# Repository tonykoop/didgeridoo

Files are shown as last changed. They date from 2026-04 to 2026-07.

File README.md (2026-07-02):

# Didgeridoo — Engineering Documentation for a Stave-Built Wind Instrument

> *A 2013 acoustic study of stave-built didgeridoos across 25 musical keys, plus the engineering documentation, CAD work, and design brainstorming that has accumulated around it since.*

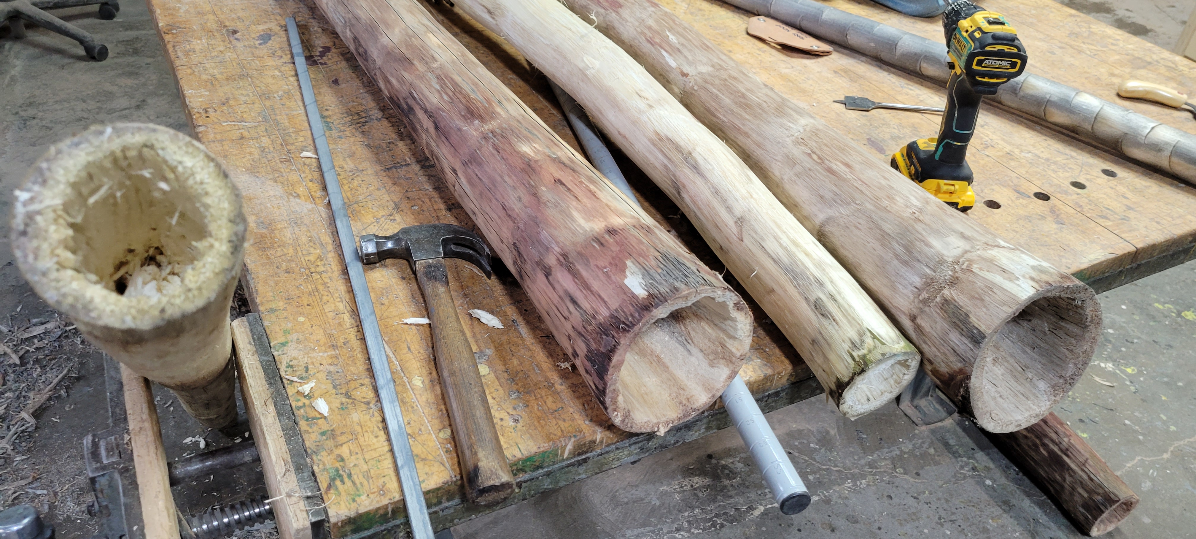
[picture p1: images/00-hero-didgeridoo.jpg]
Hero photo

*Didgeridoo blanks and rough-bored bodies on the shop bench — the physical side of the stave-built wind-instrument problem before the acoustic-length math turns into a finished bore.*

## What this is

Engineering documentation for the **stave-built didgeridoo** — a long Australian Aboriginal wind instrument that is traditionally made from a single eucalyptus branch hollowed by termites, but that I have been studying as a precision stave-construction problem since 2013.

The repository combines three threads:

1. **A 2013 acoustic study** I conducted in my engineering notebook covering 25 musical keys (C1–C3, with build lengths from ~27" at C3 up to ~107" at C1), with frequency, wavelength, build length, and stave-width calculations for each key.
2. **CAD geometry** for stave-built didgeridoo bodies derived from that table.
3. **Brainstorming and design work** on internal-surface treatments — smooth, ribbed, concentric-ringed — that shape the instrument's harmonic content.

Sister project to [`djembe`](https://github.com/tonykoop/djembe), [`dundun`](https://github.com/tonykoop/dundun), and [`ashiko-drum-workshop`](https://github.com/tonykoop/ashiko-drum-workshop).

## Background

The didgeridoo (also yiḏaki, mago, and many regional names) is a wind instrument with origins in the cultures of the **Aboriginal peoples of northern Australia**, with continuous documented use for at least 1,500 years and likely much longer. Traditional didgeridoos are made by finding a eucalyptus or bamboo branch hollowed naturally by termites, then trimming and shaping it for sound — a process that yields a unique instrument every time but offers no precise control over pitch or tone.

A **stave-built** didgeridoo is a Western maker's adaptation: rather than relying on termite excavation, the bore is built up from precisely-cut wooden staves glued in a parallel bundle. This trades the natural variability of the traditional instrument for **the ability to target a specific key, length, and bore profile by design.** It also makes locally-sourced North American hardwoods viable — oak, maple, cherry, padauk, and so on — instead of depending on Australian eucalyptus.

## The engineering challenge

A didgeridoo's fundamental frequency is set by the **acoustic length of the bore** and modified by mouthpiece, bell, and bore taper. The basic relationship for a closed-pipe (lip-blown) instrument is:

```
f ≈ c / (4 × L)
```

where `f` is fundamental frequency, `c` is speed of sound at the playing temperature (~37 °C for warm exhaled breath = ~351.8 m/s), and `L` is the effective acoustic length.

In my 2013 notebook study I calculated build dimensions for **25 keys from C1 (32.7 Hz, ~107" long) to C3 (130.8 Hz, ~27" long)**, with stave widths and inner diameters tabulated across three length-to-diameter aspect ratios: 22:1, 24:1, and 26:1. The L:D ratio governs the slenderness of the instrument — at a given length, a narrower bore (higher L:D) produces a darker tone with stronger upper harmonics; a fatter bore yields a brighter, more open sound.

The engineering interest of stave construction is precision: cutting 6, 8, or 12 staves with the right width, taper, and bevel angle to assemble into a target bore is much more controllable than excavating a branch. The stave geometry depends on the target bore diameter and stave count — calculable from the 2013 table.

## Acoustic research

The primary source for this repository is a 2013 lab-notebook entry (witnessed/signed/dated), pictured below:

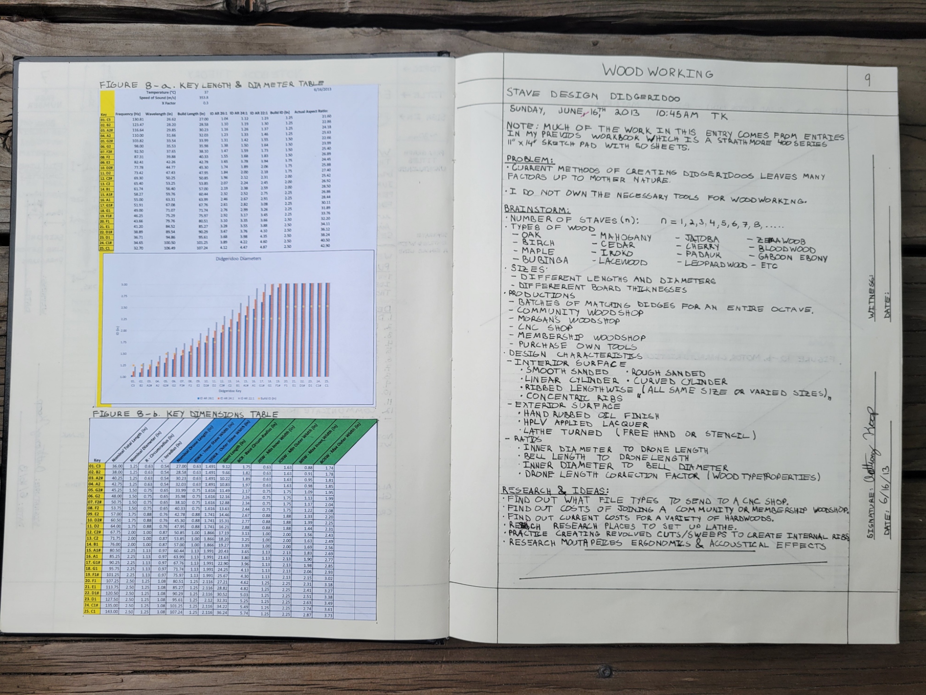
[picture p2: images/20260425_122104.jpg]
2013 didgeridoo notebook entry — Sunday June 16, 2013, page 9

*The notebook spread: Figure 8-a Key Length & Diameter Table (25 chromatic keys C1–C3), Didgeridoo Diameters bar chart, Figure 8-b Key Dimensions Table, plus brainstorming on stave count, wood species, production paths, and design characteristics. Witnessed and dated.*

Contents of that entry:

- **Figure 8-a — Key Length & Diameter Table.** 25 rows, one per chromatic key from C1 to C3, with fundamental frequency, wavelength at 37 °C, build length, ID at 26:1 / 24:1 / 22:1 aspect ratios, build ID, and actual aspect ratio.
- **Didgeridoo Diameters bar chart** — visual comparison of inner diameters across all 25 keys.
- **Figure 8-b — Key Dimensions Table.** Nominal total length, nominal diameter, outer/inner radius, drone length, stave widths (inner and outer), bevel widths, and minimum/maximum widths per key.
- **Brainstorming notes** on stave count (n = 1 through 8+), wood types (oak, mahogany, cherry, jatoba, maple, lacewood, padauk, etc.), production paths (CNC, community woodshop, Morgan's woodshop, membership shop), and design characteristics (interior surface variants, exterior finishes, bore aspect ratios).
- **Research questions** noted for follow-up: file types accepted by CNC shops, costs of various hardwoods, lathe sourcing, internal-rib practice cuts, mouthpiece ergonomics and acoustic effects.

The notebook page is the closest thing this repository has to a primary source. The entire CAD and jig design effort is downstream of that table.

## CAD and jig design

The first CAD authority pass is now scoped as a bore-station measurement
capture, not as a build-ready bore claim. See:

- `analysis/bore-station-measurement-plan.md` for datum, station, and review
  rules.
- `analysis/bore-station-station-map.csv` for normalized station IDs.
- `analysis/bore-station-measurement-log.csv` for the empty measurement table
  that must be populated before geometry authority exists.
- `CAD/bore-profile/didgeridoo-bore-starter.scad` for a non-fabrication
  OpenSCAD starter that renders station markers until measured bore diameters
  are supplied.
- `drawings/didgeridoo-bore-dxf-authority-plan.md` for the future DXF layer and
  review gate.

Repository structure is laid out for:

- `/CAD/bore-profile/` — the target inner-bore geometry for one or more keys, parametric in length and aspect ratio.
- `/CAD/stave/` — stave geometry derived from the bore profile, varying with stave count `n` and target key.
- `/CAD/jigs/` — the cutting fixtures. Likely one for the bevel angle (similar to the ashiko sled) and one for the optional internal-rib feature (a router fixture or lathe template).

## Build history

> *(Forthcoming — pulling whatever physical builds and prototype photos exist into `/images/`.)*

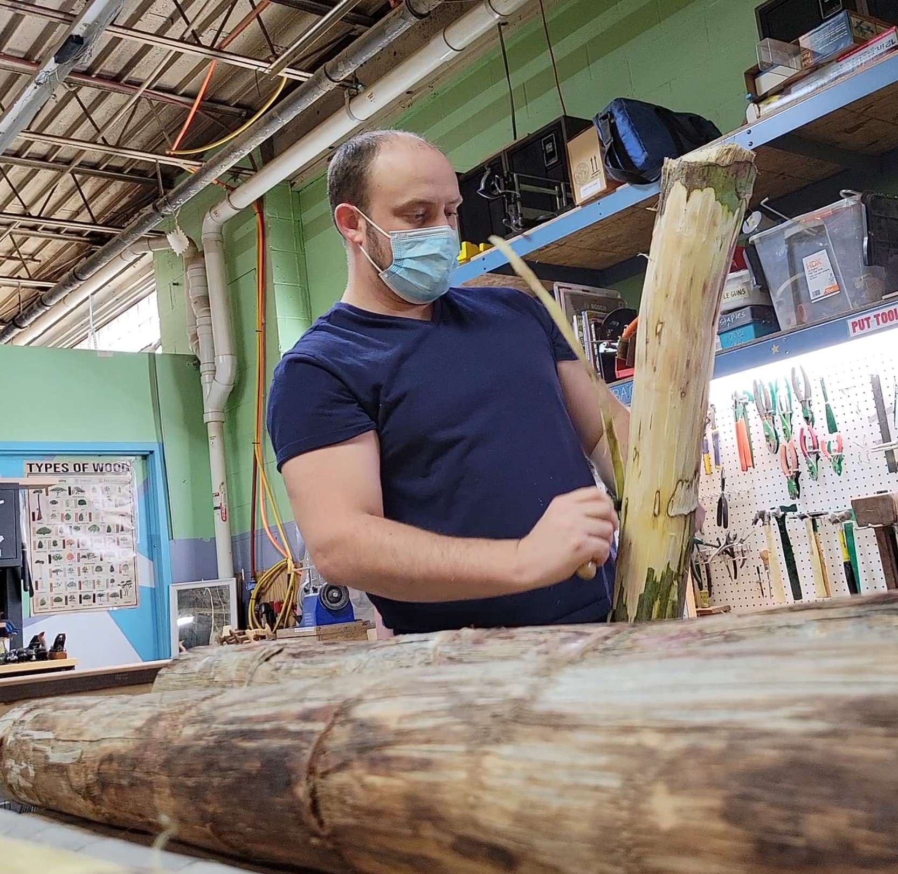
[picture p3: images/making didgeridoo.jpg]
Stripping bark from a raw didgeridoo log in the shop

*In the shop with a peeled didgeridoo log — early stage of a stave-built (or hybrid) build before the bore is established.*

## What this work is for

- **The acoustic question** — calibrating the table against measured pitch from physical builds. Does a stave-built didgeridoo built to the calculated dimensions actually play in tune?
- **The fabrication question** — which combination of stave count, wood selection, and aspect ratio produces the easiest-to-build, best-sounding instrument?
- **The portfolio frame** — for engineers and recruiters: this repository documents an analytical engineering practice (parametric design tables, bore acoustics, stave fabrication math) that I have been refining since 2013, in parallel with my professional engineering career.

## License

Released under [CC-BY 4.0](LICENSE) — use freely with attribution. The didgeridoo as an instrument originates with Aboriginal Australian cultures and has continuous traditional use; the stave-construction methodology, acoustic calculations, CAD work, and analysis in this repository are my own work, free to reuse and adapt with credit.

## Repository structure

```
didgeridoo/
├── README.md                  ← you are here
├── LICENSE                    ← CC-BY 4.0
├── .gitignore
├── research/                  ← 2013 notebook entry + acoustic refs
├── analysis/                  ← parametric calculations, FFT plots (forthcoming)
├── CAD/
│   ├── bore-profile/          ← target inner geometry, by key
│   ├── stave/                 ← stave geometry by key and stave count
│   └── jigs/                  ← bevel sled + optional internal-rib jig
├── drawings/                  ← PDF exports
├── images/                    ← finished-build photos + figures
└── reference/                 ← any reference documents
```

## Status

**Status:** L1 concept packet

Packet readiness: `L1_packet` / V5-shaped starter slice. Fabrication authority
is not released; CAD/DXF/design-table authority still requires measured bore
stations or reviewed parametric geometry.

## Starter Packet Surfaces

Open `explorer.html` for a studio-facing overview of the current bare-bones
packet. `site/index.html` redirects to that explorer until a fuller public
build-log site is ready.

Core packet files:

- `design.md` - A1 bell-flared candidate, stopped-pipe assumptions, and
  measurement-required unknowns.
- `bom.csv`, `sourcing.csv`, and `cut-list.csv` - starter planning rows only;
  purchase-time availability and prices remain unverified.
- `validation.csv` and `validation-loop.csv` - bore, pitch, leak, trim, and
  breath-contact safety gates.
- `risks.md` and `photo-shotlist.md` - validation risks and documentation shots
  for a future build.
- `capstone-manifest.json` - machine-readable inventory and public-release
  blockers.
- `evolution/` - Stage 0 evolution-pipeline intake (design intent, revision
  register, master manifest with sha256 provenance) for `CAD/didgeridoo.scad`
  and the design-table/wolfram sources it traces to. Gate A not yet run.

| Section | Status |
|---|---|
| Repo description, license, gitignore | ✓ done |
| 2013 notebook entry (primary source) | ✓ photographed and committed |
| Hero photo | forthcoming |
| Bore station measurement plan | B5 starter added; no measured bore geometry claimed |
| CAD — bore profile geometry | blocked on populated bore-station measurements |
| CAD — stave geometry | not started |
| CAD — jig designs | not started |
| Physical builds | searching personal archives |

Living document — the primary-source acoustics table is already in place; CAD geometry and recovered physical-build documentation are the main remaining additions.

See `v5-packet-alignment.md` for the current V5 gap map and issue #1 closure
boundary.
The current B5 OpenSCAD/DXF work is an authority plan and capture scaffold
only.

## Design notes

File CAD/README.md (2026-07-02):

# CAD Notes

`didgeridoo.scad` is the current parametric bore-flare **envelope** master.
Authority: `pending_measurement` — see `visual-output-register.csv` CAD-001
and `mcp-session-log.md`. It does not replace or supersede
`bore-profile/didgeridoo-bore-starter.scad`, which stays the station-capture
template for recording real measurements.

## Why an envelope, not a bore profile

Didgeridoos have a flaring bore (narrow mouthpiece end, wide bell/foot end)
rather than a tone-hole schedule. `family-spec.csv` gives real design-table
mouth ID, bell/foot ID, and blank length for three candidate bore families
(`bell`, `conical`, `cylindrical`), but `analysis/bore-station-measurement-log.csv`
is currently **fully unmeasured** — every one of the 12 stations in
`analysis/bore-station-station-map.csv` is `unmeasured`. There is no interior
taper schedule in this repo to loft from, and `design.md` only describes the
bell family's interior shape in prose ("gradual expansion from mouth opening
toward bell") with no formula.

`didgeridoo.scad` handles the three families honestly and differently:

- **cylindrical** — mouth ID equals foot/bell ID by definition. Every
  interior station is set to the design-table mouth ID exactly. No
  assumption.
- **conical** — a straight-sided cone by definition. Every interior station
  is the exact linear interpolation between the design-table mouth ID and
  foot/bell ID. No assumption (this is what "conical" means).
- **bell** — no interior-taper formula exists anywhere in this repo. The
  master exposes `bell_show_assumption_curve` (default `true`, so the file
  always renders something for shop review): when true it fills interior
  stations with one clearly-labeled `bell_flare_exponent_assumption` curve
  (an assumption, not authority); when false the interior stations fall back
  to the `-1` TBD sentinel (same convention as
  `bore-profile/didgeridoo-bore-starter.scad`) and the module renders a flat
  station-check plate instead of a solid.

## Parameters

`profile` selects one of the three `family-spec.csv` rows
(`DID-V5-A1-BELL-P0` / `DID-V5-C2-CONICAL-P0` / `DID-V5-D2-CYL-P0`).
`wall_thickness_in` (0.50 in) comes from `design.md`'s Source Basis workbook
input; `CAD/didgeridoo-openscad-authority-plan.md` still flags wall thickness
as measurement-required for the as-built prototype, so treat it as a planning
assumption, not a confirmed as-built value. `fabrication_mode` /
`measurement_reviewed` gate fabrication the same way
`bore-profile/didgeridoo-bore-starter.scad` does — flipping `fabrication_mode`
alone can never make this master fabrication authority; `measurement_reviewed`
only becomes true after a real, reviewed pass over
`analysis/bore-station-measurement-log.csv`.

Render check: `openscad -o /tmp/didgeridoo-check.stl CAD/didgeridoo.scad`
exits 0 for the default `profile = "bell"` (assumption curve on).

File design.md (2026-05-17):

# Didgeridoo V5 Starter Design

Current status: bare-bones readiness packet.

Fabrication authority: not build-ready. The existing workbook and this packet
define a measured-build starting point, not final CAD/CAM geometry. CAD/DXF
status is future authority until a measured bore profile or reviewed drawing is
added.

## Intent

V5 is a starter lift for a stave-built or split-blank didgeridoo packet. The
first useful build target is a practical A1 drone with a bell-flared bore:

- Target drone: A1, 55.00 Hz.
- Governing model: stopped pipe, `f = c / (4 * L_eff)`.
- Starter blank length: 67.50 in, using the workbook convention of theoretical
  quarter-wave length plus 6 in trim allowance, rounded up to 0.25 in.
- Mouthpiece opening: 1.50 in ID.
- Candidate bell opening: 3.50 in ID.
- Expected ideal resonances before measured correction: 165.00 Hz and
  275.00 Hz.

The A1 bell candidate is long enough to feel like a full didgeridoo and short
enough for first-round shop handling. C2 and D2 candidates are kept in
`family-spec.csv` as comparison rows, but V5 should validate one candidate
before multiplying variants.

## Source Basis

The starting values come from `didgeridoo-design-table.xlsx` and its
`Didgeridoo` worksheet:

- Speed of sound input: 343 m/s at 20 C.
- Wall thickness input: 0.50 in.
- Mouthpiece opening input: 1.50 in.
- Three bore families: cylindrical, conical, and bell.
- Build convention: cut long, then trim from the foot end to raise pitch.

The workbook formulas are treated as design evidence and planning data. They
are not enough by themselves to release a V5 build-ready packet, because the
actual mouthpiece compliance, bell end correction, bore roughness, leak path,
and player coupling have not been measured.

## Bore Profile

Recommended V5 starter profile: bell-flared A1.

Candidate profile definition:

- Mouth end: 1.50 in ID.
- Main body: gradual expansion from mouth opening toward bell.
- Bell end: 3.50 in ID.
- Length reference: 61.38 in first-order quarter-wave length at 20 C, plus
  6.00 in trim allowance in the rough blank.
- End condition: lips seal the mouthpiece end; foot/bell end is open.

Do not cut the internal bore from these notes alone. First create a station
table or CAD spline with measured datum points, then review the drawing against
the bore-profile register in `CAD/bore-profile/bore-profile-register.csv`.

## Mouthpiece

Starter mouthpiece assumption:

- 1.50 in opening at the wood body or wax ring.
- Beeswax or removable test ring for early playability.
- Final lip contact geometry is measurement-required.

Open measurements:

- Comfortable lip aperture for the intended player.
- Wax ring thickness and inner-edge radius.
- Whether the mouthpiece volume shifts the effective closed-end behavior.
- Leak check at wax/body interface after warm-up.

## Bell And End Condition

The didgeridoo is modeled as a stopped pipe: the player's lips close the mouth
end acoustically and the bell/foot is open. The bell opening is a strong
correction term, so the bell row stays preliminary until measured.

The workbook's K1 row uses an open-end correction of `0.6 * radius`. For the
3.50 in A1 bell that is 1.05 in. This packet records that as an assumption, not
as a final trim instruction. The validation loop must measure the real drone
and trim response before deciding whether to shorten the body by that amount.

## Materials And Process

Supported V5 process paths:

- PVC prototype: fastest acoustic validation of length, leak behavior, and
  mouthpiece feel.
- Agave stalk: natural-bore path when a suitable dried stalk exists.
- Split hardwood blank: CNC/lathe path for controlled bore geometry.
- Stave-built hardwood: longer-term path after the bore station table and
  stave derivation are ready.

Preferred first validation path: PVC or inexpensive split-blank mockup. Do not
spend hardwood-CNC effort before the A1 length and mouthpiece assumptions have
passed a basic pitch/leak/response test.

## Unknowns Requiring Measurement

- Actual bore ID along the full length after boring, routing, sanding, and
  finishing.
- Fundamental pitch after mouthpiece is installed and warmed by playing.
- First toot / second resonance behavior relative to the ideal 3f prediction.
- Air leak behavior at glue seams, mouthpiece, and any natural cracks.
- Finish safety inside the bore after cure, including odor, tack, dust, and
  player contact risk.
- Whether bell flare moves the response closer to the desired tone or only
  makes tuning less predictable.
- Whether the final process is cylindrical, conical, bell-flared, or a hybrid
  found-bore profile.

## Promotion Gate

This packet can become a V5 build packet only after:

- `validation-loop.csv` has measured bore and pitch rows for the chosen
  candidate.
- A CAD/DXF/design-table artifact is named as fabrication authority.
- The starter BOM has in-hand or verified purchase-time sources.
- Finish and glue choices are confirmed safe for a breath-contact instrument.
- The final design language stops saying starter/planning-only because the
  evidence supports a stronger claim.

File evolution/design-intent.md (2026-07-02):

# Design Intent — didgeridoo rev A

- Master CAD (envelope): `CAD/didgeridoo.scad` (sha256: 86219732ab9d2847231d72b28dec062c1e952f19ee1c46049314f83971c8c2bf), driven by `family-spec.csv` and `design.md`, both derived from `didgeridoo-design-table.xlsx` (sha256: 80c21687474361947217b07fb3bb809dc6939b7a2a04ae6574fa2205e11c3639).
- Station-capture template (unchanged): `CAD/bore-profile/didgeridoo-bore-starter.scad` (sha256: 347c79901ed3589102918873d560f1468f90f00a92d4371e5c93419c03eac0cb) — renders a station-check plate until `analysis/bore-station-measurement-log.csv` is populated and reviewed.
- Function: Lip-blown stopped-pipe drone instrument (didgeridoo). Player's lips acoustically close the mouthpiece end; the bell/foot end is open. Fundamental set by `f ≈ c / (4 × L_eff)`. The recommended first V5 candidate is an A1 (55.00 Hz) bell-flared bore: 1.50 in mouthpiece ID, 3.50 in bell/foot ID, 67.50 in starter blank length (61.38 in theoretical quarter-wave + 6.00 in trim allowance). Two comparison candidates (C2 conical, D2 cylindrical) are carried in `family-spec.csv` for formula validation before the bell candidate is committed to.
- Environment: breath-contact instrument (bore finish, glue, and wax touch the player's mouth/lungs — safety gate, see Must-nots). Long slender hardwood/PVC/agave bore is handled and transported end-to-end; no sustained structural load beyond its own weight and player grip.
- Target qty: 1 (prototype). Deadline: TBD. Budget/unit ceiling: TBD.

## Critical dimensions (carry tolerances)

| Feature | Nominal | Tolerance | Why critical | Source |
| --- | --- | --- | --- | --- |
| Mouthpiece bore ID | 1.50 in | measurement-required after boring/finishing | drone pitch, playability, lip seal | family-spec.csv `DID-V5-A1-BELL-P0` (design table rows 10-40) |
| Bell/foot ID | 3.50 in | measurement-required; open-end correction still an assumption | drone pitch (end correction), tone color | family-spec.csv `DID-V5-A1-BELL-P0` |
| Starter blank length | 67.50 in | cut long, trim from foot per workbook convention | drone pitch (L_eff) | family-spec.csv `DID-V5-A1-BELL-P0`; theoretical quarter-wave 61.38 in + 6.00 in trim allowance |
| Wall thickness | 0.50 in | not yet confirmed as-built | wall strength, weight, exterior/interior offset in envelope model | design.md Source Basis (workbook input); `CAD/didgeridoo-openscad-authority-plan.md` still flags as measurement-required |
| Interior bore taper (12 stations, BS-000…BS-100) | TBD (all `unmeasured`) | full measurement + review pass required before any fabrication claim | overall tone/response; distinguishes cylindrical vs. conical vs. bell in practice | analysis/bore-station-measurement-log.csv (empty template), analysis/bore-station-station-map.csv (station grid) |
| Bell interior flare shape | assumption only (`bell_flare_exponent_assumption = 2.2` in CAD/didgeridoo.scad) | replace with measured stations before any authority claim | tone/response prediction for the bell candidate | no formula exists in this repo; CAD-authored assumption, clearly labeled non-authority |
| Open-end correction (bell) | 0.6 × bell radius ≈ 1.05 in | validation-loop measurement of real drone vs. trim response | trim length decision | design.md "Bell And End Condition" (workbook K1 row convention) |

## Incidental (free for DFM)

- Exterior finish/decoration, stave count and species selection (oak, maple, cherry, padauk, etc.), non-mating cosmetic surface treatment, mouthpiece wax-ring styling once the 1.50 in opening and lip-contact geometry are set.

## Must-nots (DFM may never violate)

- Do not claim fabrication authority for any bore diameter until `analysis/bore-station-measurement-log.csv` is populated and reviewed (risks.md "Fabrication Risks"; `analysis/bore-station-authority-register.csv` AUTH-B5-004/005).
- Do not treat bore finishes, adhesives, sanding dust, or wax additives as breath-safe until product choice, cure, odor, tack, and dust checks are recorded (risks.md "Safety Risks").
- Do not machine hardwood before a PVC or scrap validation pass confirms the A1 length and mouthpiece assumptions (design.md "Materials And Process"; risks.md "Fabrication Risks").
- Do not infer toolpaths or DXF geometry from prose, photos, or the current CAD/DXF authority plans — only from a reviewed station table or reviewed CAD (drawings/didgeridoo-bore-dxf-authority-plan.md).
- Never overstate readiness (risks.md "Scope Risks": updating README status before CAD/DXF, visual register, validation rows, and MCP provenance exist would overstate readiness) — this repo stays L1 concept packet this pass.

## Material intent

- Preferred first validation path: PVC or inexpensive split-blank mockup (design.md "Materials And Process").
- Candidate build materials: PVC prototype tube, dried agave stalk, hardwood split blank (oak/maple/cherry/jatoba/padauk per README), slow-cure epoxy, beeswax mouthpiece ring, bore sealant (shellac or reviewed breath-contact finish), exterior finish — see `bom.csv` for full list (all rows `unverified_until_purchase`).
- Forbidden: none recorded yet; bore-contact finish/adhesive choices remain gated on the safety checks in `risks.md`.

## Stage status

Stage 0 intake complete 2026-07-01. Gate A (Alpha shop compile) NOT yet run — no concessions logged, nothing presented as shippable.

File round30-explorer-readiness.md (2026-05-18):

# Round 30 Explorer Readiness

Status: L1 explorer-ready starter packet, not V5 sign-off.

## Stash Reconciliation

The Round 30 stash catalog listed a didgeridoo `explorer.html` entry at
`stash@{0}`. That stashed explorer was inspected before this update.

Result: current `origin/main` already preserves the useful explorer surface and
fixes the stashed file's broken GitHub action link. No stashed content was
reapplied.

## Current Readiness

The packet is ready for review and measurement planning because it now has:

- a root `capstone-manifest.json` with repo-relative paths;
- a working `explorer.html` that surfaces packet files, authority boundaries,
  and validation gates;
- an acoustic-law family spec for the stopped-pipe didgeridoo candidates;
- a visual-output register that separates reference/planning artifacts from
  fabrication authority;
- bore-station capture scaffolding for future measured geometry.

## Authority Boundary

No fabrication authority is released by this explorer update. Bore profile,
mouthpiece, tuning, and backpressure behavior remain tied to the workbook,
starter design notes, and explicit validation gates until measured evidence or
reviewed CAD/DXF/design-table authority is added.

The `visual-output-register.csv` keeps the blank bore-station measurement log
as a validator-recognized measurement-template row. That row is an authority
slot, not measured geometry.

Required before any stronger readiness claim:

- populate and review `analysis/bore-station-measurement-log.csv`;
- record cold pitch, warmed pitch, leak checks, and trim response in
  `validation-loop.csv`;
- promote a reviewed CAD, DXF, measured station table, or design table in
  `visual-output-register.csv`;
- record breath-contact finish, glue, wax, cure, odor, dust, and tack safety;
- add actual MCP session rows for generated V5 CAD/render/plate artifacts.

## Next Explorer Promotion

The next useful explorer change is not more prose. It should be a measured
station table or reviewed design-table export that lets the explorer show a
named authority source without overstating the current starter packet.

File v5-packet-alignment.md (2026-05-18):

# V5 Packet Alignment

Status: V5-shaped starter slice, not V5 sign-off.

## Readiness

Readiness label: `L1_packet`.

This packet is reviewable because it has repo-root packet files, an acoustic
family spec, visual authority boundaries, validation gates, Wolfram/acoustic
notes, and a starter MCP provenance log. It is not build-ready because the
selected bore has not been measured, no CAD/DXF artifact has been promoted to
fabrication authority, and no prototype pitch/leak results are logged.

## Issue #1 Closure Target

PR #2 should continue to use `Refs #1`, not `Closes #1`.

Reason: issue #1 requires all V5 deliverables, including parametric CAD,
vector design plates, a render, an annotated print plate, and an MCP log with
design-session provenance. This starter slice materially advances the issue but
does not satisfy the full acceptance gate.

## Current V5 Coverage

| V5 area | current artifact | status | next gate |
| --- | --- | --- | --- |
| V4 packet files | `design.md`, `bom.csv`, `sourcing.csv`, `cut-list.csv`, `validation.csv`, `risks.md`, `drawing-brief.md`, `photo-shotlist.md` | present | review for completeness |
| Acoustic family spec | `family-spec.csv` | present, validator-clean | add measured bore and pitch evidence |
| Visual authority | `visual-output-register.csv` | reference photos only | add CAD/DXF rows only after authority exists |
| CAD authority plan | `CAD/didgeridoo-openscad-authority-plan.md` | plan only | create reviewed `CAD/didgeridoo.scad` or station table |
| MCP provenance | `CAD/mcp-session-log.md` | starter log | add rows from actual design MCP sessions |
| Bore measurement gates | `validation.csv`, `validation-loop.csv` | present | record station ID, pitch, leak, trim, and safety evidence |
| Wolfram/acoustics | `analysis/wolfram-study-notes.md` | scoped calculation notes | add measured-data sensitivity study |

## Round 30 Explorer Readiness

`round30-explorer-readiness.md` records the stash reconciliation and current
explorer promotion boundary. The stashed `explorer.html` was older than
current main because current main already contains the useful explorer surface
plus the repaired GitHub action link.

This update keeps the packet at `L1_packet`. The explorer is review-ready, but
the next promotion still depends on measured bore stations, pitch/leak logs,
breath-contact safety evidence, and reviewed CAD/DXF/design-table authority.

## Authority Boundary

Fabrication authority remains unreleased. The workbook, README, design notes,
photos, and current registers are planning evidence. The first possible
authority artifact should be a measured bore station table, reviewed OpenSCAD
master, reviewed DXF, or reviewed design table.

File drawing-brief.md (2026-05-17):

# Drawing Brief

Current status: bare-bones readiness packet. Fabrication authority is not
released from these notes.

## Required Future Drawings

| drawing_id | artifact | purpose | authority_target | prerequisite_evidence |
| --- | --- | --- | --- | --- |
| DRW-001 | `drawings/didgeridoo-bore-profile.svg` | readable bore station preview | derived_preview | measured station CSV or reviewed design table |
| DRW-002 | `drawings/didgeridoo-bore-profile.dxf` | shop/CNC bore authority | fabrication | reviewed bore CAD with traceable dimensions |
| DRW-003 | `CAD/didgeridoo.scad` | parametric master geometry | fabrication | selected candidate, station table, end-correction decision |
| DRW-004 | `print-packet/assembly-plate.pdf` | annotated build plate | derived_preview | DRW-002 or DRW-003 promoted to authority |

## Authority Boundary

The current workbook, `family-spec.csv`, and
`CAD/bore-profile/bore-profile-register.csv` describe planning values and
review gates. They do not authorize cutting a final didgeridoo body.

The first authority candidate should be a measured bore station table or
reviewed parametric CAD model. Any SVG, PDF, render, or hero image produced
before that point is a preview or reference image only.

The repo currently uses `CAD/` rather than lowercase `cad/`; keep new starter
CAD notes there unless a future layout-only migration changes the directory
convention.

## Drawing Checks

- Every critical dimension must trace back to `family-spec.csv`,
  `cut-list.csv`, or a measured station table.
- Any DXF/CAD artifact promoted to fabrication authority must be added to
  `visual-output-register.csv`.
- Rendered or generated images must stay `concept_only` or `reference_only`
  and must not supply dimensions, toolpaths, or bore stations.

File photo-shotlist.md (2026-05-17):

# Photo Shotlist

Current status: optional public documentation shots for a future validation
build. These shots are not fabrication authority.

| shot_id | subject | purpose | required_before_v5 | privacy_notes |
| --- | --- | --- | --- | --- |
| PHO-001 | full rough blank beside tape measure | document starting length and material | yes | avoid home/location details |
| PHO-002 | mouthpiece opening with scale | capture lip-contact starting geometry | yes | no face required |
| PHO-003 | bell/foot opening with scale | document open-end measurement basis | yes | keep scale readable |
| PHO-004 | bore station measurement setup | support bore station table provenance | yes | show tool, not private workspace details |
| PHO-005 | tuner or spectrum readout during cold test | support validation-loop pitch row | yes | crop unrelated device notifications |
| PHO-006 | seam/leak inspection setup | support leak gate | yes | no private labels or addresses |
| PHO-007 | finished exterior overview | public project documentation | no | optional after safety and finish checks |

Record the file path, date, and related validation row when any shot is added.

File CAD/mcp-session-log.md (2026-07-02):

# MCP Session Log

Status: starter provenance log, not V5 sign-off.

This repository currently has no recorded Claude Desktop MCP design session
that produced OpenSCAD, Blender, Illustrator, Photoshop, DXF, SVG, render, or
print-packet artifacts. The log exists so future V5 work has a stable audit
trail before any generated CAD or visual output is promoted.

The repo already uses the uppercase `CAD/` directory. Issue #1 names
`cad/mcp-session-log.md`; this starter keeps the log in `CAD/` to avoid a
case-only directory split on Windows filesystems. If the repo later migrates
to lowercase `cad/`, move this file in the same layout change.

| timestamp_utc | tool | artifact | claude_session_id | notes |
| --- | --- | --- | --- | --- |
| 2026-05-17T15:54:14Z | Codex CLI repo edit, no design MCP | `CAD/mcp-session-log.md` | n/a | Starter provenance log created. No CAD/Blender/Illustrator/Photoshop MCP-generated artifact exists yet, so no V5 MCP artifact is claimed. |
| 2026-07-01T00:00:00Z | claude-code (Fable 5) | `analysis/bore-station-measurement-log.csv`, `analysis/bore-station-station-map.csv`, `analysis/bore-station-authority-register.csv`, `family-spec.csv`, `bom.csv`, `sourcing.csv`, `cut-list.csv`, `validation.csv` | fable-v5-refresh-2026-07-01 | V5 refresh pass, role=packet_refresh, input_authority=didgeridoo-design-table.xlsx, authority_result=fabrication, review_status=self_checked. Tabular packet data reviewed against design-table/family-spec baseline; no dimension changes made. Provenance row added to satisfy V5 fabrication-artifact logging for `analysis/bore-station-measurement-log.csv` (measurement_template, still fully unmeasured — this row records review, not new measurements). |
| 2026-07-01T00:00:00Z | claude-code (Fable 5) + OpenSCAD CLI | `CAD/didgeridoo.scad` | fable-v5-refresh-2026-07-01 | role=cad_authoring, input_authority=family-spec.csv + design.md (didgeridoo-design-table.xlsx-derived), authority_result=pending_measurement, review_status=self_checked. Parametric bore-flare envelope master: cylindrical/conical stations are exact-by-definition from the design-table mouth/bell IDs; bell-family interior stations use one labeled ASSUMPTION flare curve (no interior taper data exists in this repo yet) and fall back to a 2D station-check plate if the assumption curve is disabled. openscad render check: pass (openscad -o STL, exit 0, default bell profile). Does not supersede or modify `CAD/bore-profile/didgeridoo-bore-starter.scad`, which remains the station-capture template for actual measurements. |
| 2026-07-01T00:00:00Z | pre-existing (verified, not generated this pass) | `wolfram/didgeridoo-bore-acoustics.wl` | fable-v5-refresh-2026-07-01 | role=analysis_source, authority_result=derived_preview, review_status=unreviewed. Source-only stopped-pipe acoustics starter; not executed (no wolframscript run this pass, per V5 refresh scope). Verified `visual-output-register.csv` row WL-001 now points at it. |

## Required Future Rows

Add one row per MCP session that produces or modifies a design artifact:

- OpenSCAD MCP or equivalent parametric CAD session for `CAD/didgeridoo.scad`.
- Blender session for any render or STL-derived preview.
- Illustrator session for SVG design plates and DXF export.
- Photoshop or Illustrator session for `print-packet/assembly-plate.pdf`.

Generated images, renders, SVG previews, or print plates remain non-authority
unless their dimensions trace to the promoted CAD, DXF, design table, or
measured station table recorded in `visual-output-register.csv`.

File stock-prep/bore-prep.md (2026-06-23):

# Split-and-Glue Bore-Prep Method

Document the full chain for preparing a clean, uniform bore from agave or yucca stalk sections. Covers split, pith removal, and glue-up. This method is needed when the natural interior is too irregular, obstructed by pith, or too small to use as-is.

> **Dust safety:** Agave gouging and sanding releases calcium-oxalate raphides. Wear a P100/N95 respirator, safety glasses, and long sleeves throughout. See `safety/agave-dust.md`.

---

## 1. When to Use This Method

| Stalk type | Bore condition | Action |
|---|---|---|
| Agave | Natural hollow, mostly clear, diameter acceptable | Inspect and clean in-place — split not required |
| Agave | Natural hollow but irregular, nodal constrictions, debris | **Split-and-glue** (this method) |
| Yucca | Pithy interior fills the bore | **Split-and-glue required** — yucca has no natural hollow |
| Either | Bore diameter too small for the target instrument | Split-and-glue to gouge a larger bore |

---

## 2. Species Differences

| Property | Agave | Yucca |
|---|---|---|
| Interior | Hollow, fibrous ring at wall, usually open | Dense pith (white spongy core) fills entire bore |
| Pith removal | Minor clean-up of fibrous residue at nodes | Full pith gouge required end-to-end |
| Wall hardness | Harder outer cortex, softer inner layer | Denser and harder; holds shape better after split |
| Splitting tendency | Splits longitudinally along natural grain | Splits cleanly; pith resists uncontrolled cracks |
| Glue-up notes | Seal fibrous inner face before gluing | Pith-free walls bond well; mating faces need to be flat |

---

## 3. Tools and Materials

- **Splitting:** Hand saw or band saw (for a clean kerf split), or a mallet + splitting wedge for a natural grain split on agave
- **Gouging:** Curved gouge (1/2–3/4 in), spoon gouge, or Dremel with drum-sander attachment
- **Sanding:** 60-grit and 120-grit sandpaper or drum-sander
- **Measuring:** Calipers, bore gauge, or a dowel as a go/no-go gauge
- **Adhesive:** Titebond III (waterproof PVA) or epoxy for structural gaps
- **Clamping:** Hose clamps (preferred for round cross-sections), band clamps, or rubber straps; min. 4 clamps per foot of length
- **Sealing (agave):** Thin CA glue or shellac to stabilise fibrous inner face before final glue-up

---

## 4. Step-by-Step Procedure

### Step 1 — Mark the Split Line

1. Identify the natural split axis: agave often has a visible grain line running longitudinally; yucca can be split along any axis.
2. Mark a straight chalk line from end to end along the intended split plane.
3. The split line should pass through the centre of the bore (or estimated pith centre for yucca).

### Step 2 — Split the Stalk

**Option A — Saw split (recommended):** Use a band saw or table saw with the chalk line as a fence guide. Cut in one pass for a flat, clean mating face. Produces two half-shells.

**Option B — Wedge split (agave only):** Score a 1/4-in kerf with a hand saw at each end, then drive a splitting wedge (chisel or wooden froe) along the grain. Faster but less flat; requires more sanding to true the faces.

### Step 3 — Pith Removal

**Agave:** Remove fibrous nodal plugs with a curved gouge. Scrape loose fibre from the inner wall. The hollow should already exist; this step clears debris and constrictions.

**Yucca (full pith gouge):**
1. With the stalk split open, the pithy core is exposed. Use a curved gouge or spoon gouge to remove pith in passes, working from the centre outward.
2. Target bore diameter: match the bore profile for the intended instrument (e.g., 1.5 in mouth ID tapering to 3.5 in bell for a standard didge blank).
3. Leave 1/8–1/4 in of pith against the wall as a reference layer; final dimension is established by sanding, not aggressive gouging.
4. Check diameter at 6-in intervals with calipers as you work.

### Step 4 — True the Bore

1. Sand the interior with 60-grit, then 120-grit, working along the bore axis (not across it).
2. Check roundness: roll a properly-sized dowel or bore gauge through the interior — it should pass without catching.
3. Remove any remaining high spots or pith remnants.
4. For agave: apply a thin coat of thin CA glue or shellac to the fibrous inner surface; let cure fully before gluing up. This prevents glue absorption into the fibre.

### Step 5 — True the Mating Faces

1. Lay each half-shell face-down on a flat surface (a jointer, belt sander, or hand plane on a known-flat reference).
2. Sand or plane the mating faces flat and straight. Check with a straightedge: gap < 0.01 in (no visible daylight) along the full length.
3. A gap here will telegraph into the bore after glue-up.

### Step 6 — Dry Fit

Bring the two half-shells together without glue. Check:
- Mating faces seat fully with hand pressure only
- No twist (ends align)
- Bore profile is symmetric and continuous
- Overall OD is round when closed (no oval cross-section)

Adjust faces if needed before proceeding.

### Step 7 — Glue-Up

1. Apply Titebond III or epoxy to both mating faces — thin, even coat; do not pool into the bore.
2. Align and close the joint. Apply clamps starting from the middle, working outward in alternating directions to prevent cupping.
   - Hose clamps at 4–6 in intervals
   - Snug but not crushing — overtightening distorts the bore
3. Wipe squeeze-out from the bore interior immediately with a damp cloth on a long dowel.
4. Cure time:
   - Titebond III: 24 h open time for repositioning, 24 h clamped, 24 h unclamped before stress
   - Epoxy (if used for large gaps): per manufacturer — typically 24 h to demold, 72 h full cure

### Step 8 — Post-Cure Bore Check

1. Remove clamps after full cure.
2. Check bore diameter end-to-end with calipers at 6-in intervals.
3. Light any surface glue ridges inside the bore with a round file or fine drum-sander.
4. Verify: a suitable bore gauge or dowel passes through the full length without catching.
5. Check the glue line on the exterior: no visible gaps. If gaps exist, fill with CA glue or thin epoxy and re-sand.

---

## 5. Bore Uniformity Acceptance Criteria

| Check | Pass |
|---|---|
| Diameter variation along length | Smooth, predictable taper; no abrupt steps > 1/8 in over 2 in |
| Roundness | ≤ 1/8 in out-of-round at any cross-section |
| Glue-line interior | Flush or < 1/32 in proud; no catching on a bore gauge pass |
| Surface condition | No loose fibres, pith chunks, or debris inside bore |

---

## Cross-References

- Stalk grading before bore prep: `stock-prep/material-spec.md`
- Cure verification before splitting: `stock-prep/cure-check.md`
- Dust/raphide safety: `safety/agave-dust.md`
- Rainstick variant (pith retained, not gouged): `builds/yucca-rainstick.md`

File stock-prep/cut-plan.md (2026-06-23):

# Multi-Cut Yield Planner — Base / Mid / Upper

Plan 2–3 instruments from a single tall agave or yucca stalk by dividing it into cut zones before making any saw cuts. Maximises yield and assigns each zone to the instrument it is best suited for acoustically and structurally.

---

## 1. Stalk-Height Classes

| Class | Dried stalk length | Typical yield |
|---|---|---|
| **Tall** | ≥ 96 in (8 ft) | 2–3 instruments + trim offcuts |
| **Short** | 48–95 in (4–7 ft 11 in) | 1 instrument + possible rainstick/flute offcut |
| **Stub** | < 48 in (< 4 ft) | Rainstick or flute blank only |

Measure the dried stalk end-to-end before zoning. The base end is the widest, heaviest end (root side); the upper end is the narrowest (tip side).

---

## 2. Cut Zones (Tall Stalk ≥ 8 ft)

```
BASE                              UPPER (tip)
|<--- Base/Bell zone --->|<--- Mid zone --->|<--- Upper zone --->|

Widest OD                                            Narrowest OD
Heaviest wall                                        Lightest wall
```

| Zone | Portion of stalk length | Expected OD range | Primary instrument |
|---|---|---|---|
| **Base / Bell** | Bottom 40–50 % | 3.5–6 in | Didgeridoo (bell/bore source) |
| **Mid** | Middle 30–40 % | 2.5–4 in | Didgeridoo (upper bore) or rainstick |
| **Upper** | Top 20–25 % | 1.5–3 in | NA flute blank or rainstick |

> **Overlap rule:** Zones are guidelines, not fixed fractions. Let wall thickness and taper (see `material-spec.md`) drive where exactly you cross-cut. Move the base/mid boundary up or down by 4–6 in to land on a section that passes the wall-thickness check.

---

## 3. Zone → Instrument Assignments

### 3a. Tall stalk — 3-instrument split

```
Stalk length example: 120 in

BASE/BELL zone: 0–54 in     → Didgeridoo blank (A1–Bb1 range)
MID zone:       54–96 in    → Second didgeridoo (higher key, shorter bore) or rainstick
UPPER zone:     96–120 in   → NA-flute blank or rainstick
Trim/kerf loss: ~2 in total across two cross-cuts
```

### 3b. Tall stalk — 2-instrument split (conservative)

```
BASE/BELL zone: 0–60 in     → Didgeridoo blank
UPPER zone:     60–120 in   → Rainstick (full-length, good cascade)
Trim/kerf loss: ~1 in
```

### 3c. Short stalk — 1-instrument split

```
Full stalk: 60–95 in        → Single didgeridoo blank (may require acoustic shortening)
No secondary cut
```

---

## 4. Cut-Point Selection

1. Lay the stalk horizontally on sawhorses. Mark the intended cut lines with chalk or tape before cutting.
2. At each proposed cut, measure:
   - OD at that point (should be ≥ 2 in for a playable bore)
   - Wall thickness (must be ≥ 1/4 in — see `material-spec.md`)
   - Check for knots, cracks, or narrowing that would weaken the cut zone
3. Adjust the cut line ± a few inches to avoid structural weak points.
4. Use a fine-tooth cross-cut saw or band saw. Protect against agave dust (see `safety/agave-dust.md`).

---

## 5. Yield Expectations

| Stalk height | Instrument yield | Notes |
|---|---|---|
| Tall (≥ 8 ft) | **2–3 instruments** | Base → didge, mid → didge or rainstick, upper → flute or rainstick |
| Short (4–7 ft) | **1 instrument + possible offcut** | Usually one full didge; upper trim may yield a small flute blank |
| Stub (< 4 ft) | **1 rainstick or flute only** | Not enough length for a didge in the A1–E1 range |

Typical kerf and trim waste per cross-cut: 1/4–1/2 in. Budget 2–3 cuts for a tall stalk → 1 in total waste.

---

## 6. Waste / Offcut Notes

- **End trim (1–2 in each end):** Remove damaged, weathered, or cracked end grain before zoning. These scraps are good test pieces for the knuckle-tap cure check.
- **Mid-cut offcuts (< 6 in):** Too short for instruments; useful as bore-diameter gauge samples or dust-collection test media.
- **Failed-zone pieces:** Sections that fail the wall/taper check can still be used as percussion shakers (fill with seeds) or left as garden stakes — no-waste principle.

---

## 7. Recording the Cut Plan (A6 Log)

```
Stalk ID: ___________   Species: [ ] agave  [ ] yucca   Length: ______ in
Height class: [ ] tall (≥8 ft)  [ ] short  [ ] stub

END TRIMS
  Base end trim: ______ in      Upper end trim: ______ in

CUT LINES (measure from base end)
  Cut 1 at ______ in → Base/Bell zone ends here
  Cut 2 at ______ in → Mid zone ends here (if 3-instrument split)

ZONE ASSIGNMENTS
  Base/Bell (0–______): ____________________
  Mid (______–______): ____________________ (if applicable)
  Upper (______–end): ____________________

Notes:
```

---

## Cross-References

- Stalk grading before cutting: `stock-prep/material-spec.md`
- Cure verification: `stock-prep/cure-check.md`
- Bore prep after cutting: `stock-prep/bore-prep.md`
- Rainstick build (upper zone): `builds/yucca-rainstick.md`
- NA-flute build (upper zone): `builds/yucca-na-flute.md`
- Dust safety during cross-cutting: `safety/agave-dust.md`

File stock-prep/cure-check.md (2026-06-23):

# Knuckle-Tap / Cure-Verification QA Check

A simple acoustic and visual field test to confirm that an agave or yucca stalk is fully cured and structurally ready for instrument work. No tools required. Do this check before grading (see `material-spec.md`) and again immediately before any bore prep.

---

## 1. Knuckle-Tap Sound Test

This is the primary cure indicator.

**How to perform:**
1. Hold the stalk horizontally with one hand near the centre, letting it hang freely (don't grip it tightly — you want it to ring, not be damped).
2. Knock firmly on the outer cortex with a single knuckle at several points: base end, mid-stalk, and upper end.
3. Listen to the sound produced.

| Sound | Interpretation | Action |
|---|---|---|
| **Clear, hollow ring** — bright, resonant knock, slight sustain | Cured: internal moisture has escaped, wall is hard and dry | PASS — proceed to grading |
| **Dull thud** — low, flat, no sustain | Green or under-cured: moisture still present; cells not yet hardened | FAIL — return to drying; recheck in 2–4 weeks |
| **Soft knock, no resonance** — sounds like tapping soft wood | Rot, fungal damage, or collapsed wall section | REJECT — do not use; inspect for visible rot |
| **Crackling or hollow thump at one spot only** — otherwise rings clear | Localised delamination or internal crack | CONDITIONAL — mark the spot; cut planning must avoid this zone |

Repeat at 6-in intervals along the stalk length. The sound should be consistent from base to upper end; abrupt changes indicate a problem zone.

---

## 2. Visual Cues

Supplement the tap test with these visual checks:

| Feature | Cured (pass) | Under-cured or problem (fail/hold) |
|---|---|---|
| Skin colour | Straw, tan, grey-tan, or silvered; uniform | Green patches, dark damp zones, brown wet spots |
| Surface texture | Papery, slightly rough, hard to fingernail scratch | Soft, yielding to fingernail, waxy feel |
| Shrinkage cracks | Fine longitudinal hairline cracks along grain — normal | Cross-grain cracks, spiral cracks, or cracks wider than 1/8 in |
| Cut-end grain | Dry, pale, visible ring structure; hard to the touch | Dark, moist, or soft at the cut face |
| Smell | Faint dusty or plant smell at most | Mildew, sour, or ammonia smell — indicates fungal or rot activity |

---

## 3. End-Grain Moisture Check (Optional Confirmation)

If you have a pin-type wood moisture meter, press the pins into the cut end grain.

| Reading | Interpretation |
|---|---|
| ≤ 12 % MC | Cured — instrument-grade |
| 13–18 % MC | Marginal — extend drying, recheck |
| > 18 % MC | Under-cured — not ready |

Agave and yucca are not wood, so moisture-meter calibration is approximate. Use as a secondary check only, not as the sole pass criterion.

---

## 4. When to Re-Check

- **Harvest to cure:** freshly cut agave or yucca stalks need 4–12 weeks of open-air drying depending on diameter, climate, and species. Larger diameter = longer cure.
- **After field storage:** check again if stalks have been stored outdoors, in humid conditions, or in contact with soil.
- **Before bore prep:** re-run the tap test on the specific cut section just before splitting — a section that passed at harvest may have absorbed moisture during storage.

---

## 5. Quick Field Checklist

```
Stalk ID: ___________   Date: ___________   Species: [ ] agave  [ ] yucca

KNUCKLE-TAP (check each zone)
  Base end tap:     [ ] Clear ring   [ ] Dull thud   [ ] Soft/no resonance
  Mid-stalk tap:    [ ] Clear ring   [ ] Dull thud   [ ] Soft/no resonance
  Upper end tap:    [ ] Clear ring   [ ] Dull thud   [ ] Soft/no resonance

VISUAL
  [ ] Skin colour — straw/tan/grey, no green patches
  [ ] Surface hard — no fingernail yield
  [ ] Cracks longitudinal only, < 1/8 in wide
  [ ] Cut-end grain dry and pale
  [ ] No mildew or sour smell

Moisture meter (if available): ______ % MC

VERDICT:  [ ] CURED — proceed  [ ] HOLD — extend drying ______ weeks  [ ] REJECT

Notes:
```

---

## Cross-References

- Grading rubric (next step after cure-check): `stock-prep/material-spec.md`
- Harvest and storage SOP: link from makerspace harvest record (A6 log)
- Dust safety during end-grain check with tools: `safety/agave-dust.md`

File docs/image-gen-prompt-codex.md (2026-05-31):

# Image Generation Prompt

Concept visualization only. Do not treat generated images as dimensional, tuning, CAD, DXF, or fabrication authority.

## Hero Prompt

Photorealistic studio product photograph of a finished stave-built didgeridoo concept, a long low-drone lip-blown wooden tube assembled from visible tapered hardwood staves with a subtle bell flare, warm oil finish, smooth mouthpiece ring, and faint evidence of a carefully controlled bore rather than a natural branch. Show the full length diagonally across a clean studio floor with a small bench block and calipers for scale, soft directional studio lighting, three-quarter product-photography angle from the mouthpiece toward the bell, about a 50mm lens, high detail, photorealistic.

## In-Context Prompt

Photorealistic workshop scene of the stave-built didgeridoo on supports beside rough-bored halves, stave offcuts, a notebook with acoustic-length sketches but no readable text, and sanding tools. Natural shop light, realistic hardwood grain, the object reads as an engineered didgeridoo study with controlled bore and optional internal-surface experiments, not a traditional eucalyptus artifact.

## Detail/Macro Prompt

Macro detail of the didgeridoo bell and stave seams: alternating hardwood grain, tight glue lines, polished inner rim, subtle flared opening, hand-rubbed finish, faint rib or smooth-bore test texture visible just inside the mouth of the bell, photorealistic high detail with shallow depth of field.

## Negative / Avoid

Avoid cultural misrepresentation, ceremonial markings, logos, watermarks, impossible bore openings, cracks presented as decoration, readable text, and fake traditional provenance.

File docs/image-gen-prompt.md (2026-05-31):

# Image-Gen Prompts

Concept image only; not fabrication authority. Do not include cut-ready dimensions, hole locations, or toolpaths.

## Hero Prompt

A long, slender stave-built didgeridoo presented as a finished physical object: a roughly chest-high straight wooden wind instrument, slightly longer than a person is tall when stood upright, with a narrow mouth end that gently widens through the body into a softly flared bell at the foot. The body reads as a parallel bundle of precisely-cut hardwood staves glued into a tube and turned smooth — visible long-grain seams running the full length where the staves meet, in warm North American hardwoods such as oak, maple, cherry, or padauk with subtle color variation between staves. The mouth end carries a small smooth ring of beeswax forming the lip-contact mouthpiece; the foot end opens into a clean bell mouth. Matte hand-rubbed oil finish on the exterior, bore interior in shadow. Lying on a clean neutral light-gray studio sweep with a discreet wooden bench-block under it for scale, soft directional studio light raking along the staves to reveal the glue seams and grain, three-quarter product-photography angle, ~50mm lens, high detail, photorealistic, no text labels.

## In-Context Prompt

The same stave-built hardwood didgeridoo staged upright in a woodworker's shop, leaning at a low angle against a bench beside a peeled raw didgeridoo log and a few rough stave blanks, telling the story of the build path from blank to bored body. Sawdust and hand tools softly out of focus in the background, warm late-afternoon window light, shallow depth of field holding focus on the flared bell and the stave seams, concept visualization only, photorealistic.

## Detail Prompt

Macro close-up of the stave seam and bell flare: the surface where adjacent glued hardwood staves meet along a near-invisible glue line, the grain of two differently-colored hardwoods abutting, sweeping toward the gently widening bell opening at the foot of the instrument. Raking low-angle light grazing across the wood to bring out the bevel between staves and the smoothness of the turned exterior, fine wood pore texture, high detail, no measurements.

## Negative / Avoid

No text, logos, watermarks, or fake maker marks; no painted Aboriginal dot-art or culturally appropriated decoration; no dimension callouts or measurement lines; no impossible mechanisms or finger holes (a didgeridoo has none); anatomically plausible hands if a player is shown.

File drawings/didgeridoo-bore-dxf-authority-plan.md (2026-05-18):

# Didgeridoo Bore DXF Authority Plan

Status: DXF plan only. No cut-ready DXF is present.

## Required Layers

| Layer | Purpose | Authority Source |
| --- | --- | --- |
| `DATUM` | mouthpiece plane, foot plane, station centerlines | reviewed bore station log |
| `FAB_GEOMETRY` | bore envelope or split-blank route line | reviewed station diameters |
| `DIMENSION` | station labels and diameter callouts | reviewed station diameters |
| `NOTES` | source artifact IDs, units, review status | authority register |

## Required Review Before Export

- Confirm the selected blank or design-table row.
- Confirm actual body length and station axial positions.
- Confirm major/minor ID measurements and repeat count at every required
  station.
- Decide whether the first DXF is a centerline/bore envelope, a split-blank
  CNC pocket path, or a printed inspection plate.
- Add the exported DXF to `visual-output-register.csv` with
  `artifact_kind=dxf`, `authority=fabrication`, and a `derived_from` pointer to
  the reviewed measurement source.

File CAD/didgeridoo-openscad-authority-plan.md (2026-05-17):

# Didgeridoo OpenSCAD And DXF Authority Plan

Status: CAD authority plan only. No build-ready geometry is released here.

## Readiness Label

Current packet readiness: `L1_packet`.

Reason: the repo now has a reviewable starter packet, family specification,
validation gates, and provenance placeholders, but it does not yet have
measured bore stations, reviewed CAD/DXF, or physical tuning evidence.

## Folder Convention

The repository already uses `CAD/` for engineering assets. Issue #1 names a
lowercase `cad/<instrument>.scad`, but creating both `CAD/` and `cad/` would be
fragile on Windows checkouts. This plan uses `CAD/didgeridoo.scad` and
`CAD/bore-profile/` unless a later layout-only change migrates the repo.

## Future OpenSCAD Master

Target file: `CAD/didgeridoo.scad`.

The first OpenSCAD master must expose every critical value as a named
parameter. No dimension should appear as an unexplained literal in geometry.

| parameter | starter value | source | authority status |
| --- | ---: | --- | --- |
| `target_frequency_hz` | 55.00 | `family-spec.csv` row `DID-V5-A1-BELL-P0` | planning only |
| `mouth_bore_id_in` | 1.50 | `family-spec.csv` | measurement-required |
| `foot_bell_id_in` | 3.50 | `family-spec.csv` | measurement-required |
| `quarter_wave_length_in` | 61.38 | `family-spec.csv`, checked in `analysis/wolfram-study-notes.md` | planning only |
| `starter_blank_length_in` | 67.50 | `family-spec.csv`, workbook trim convention | planning only |
| `station_spacing_in` | TBD | future bore station table | measurement-required |
| `wall_thickness_in` | TBD | physical stock, design table, or reviewed drawing | measurement-required |

## Required CAD Inputs Before Fabrication Authority

1. Record a bore station table at 3-6 in spacing for the selected prototype or
   reviewed design.
2. Record actual mouthpiece opening and wax/body interface dimensions.
3. Record foot/bell ID and the open-end correction assumption used for the
   selected bore profile.
4. Decide whether the first authority file is a measured station CSV,
   `CAD/didgeridoo.scad`, `CAD/bore-profile/v5-a1-bell.dxf`, or a design
   table.
5. Add the promoted authority artifact to `visual-output-register.csv` with
   `authority=fabrication` only after review.

## DXF Export Gate

Target file: `CAD/bore-profile/v5-a1-bell.dxf`.

The DXF must be derived from reviewed station data or the OpenSCAD master. It
must not be traced from concept images, shop photos, or prose. Until the DXF
exists and is reviewed, `CAD/bore-profile/bore-profile-register.csv` remains a
planning register rather than fabrication geometry.

## Wolfram/Acoustic Link

The current Wolfram note checks first-order stopped-pipe lengths only. The next
notebook or `.wl` script should add:

- end-correction sensitivity for the selected bell ID;
- trim increment versus cents change near A1;
- measured cold and warmed pitch comparison;
- toot/response comparison against ideal odd harmonics.

No Wolfram plot or notebook output should become fabrication authority unless
the governing dimensions also appear in the promoted CAD, DXF, design table, or
measured station table.

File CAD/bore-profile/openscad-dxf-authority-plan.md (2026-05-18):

# OpenSCAD And DXF Authority Plan

Status: starter authority plan, not measured geometry.

## Source Chain

1. `analysis/bore-station-station-map.csv` defines normalized capture stations.
2. `analysis/bore-station-measurement-log.csv` records measured diameters,
   ovality, wall thickness, tool, conditions, and photo evidence.
3. A reviewed export from the populated log becomes the only source allowed to
   populate `measured_inner_diameter_in` in
   `CAD/bore-profile/didgeridoo-bore-starter.scad`.
4. A DXF export is allowed only after every required station has positive,
   reviewed dimensions and the exported file is recorded in
   `visual-output-register.csv`.

## OpenSCAD Starter Behavior

The current SCAD file renders a station-check plate. It intentionally uses
`-1` sentinel values for all bore diameters. If `fabrication_mode` is set to
`true` before measured values are supplied, the file asserts and refuses the
fabrication path.

## DXF Gate

The first fabrication DXF should be named
`drawings/didgeridoo-bore-profile.dxf` and must include:

- a mouthpiece datum,
- a foot datum,
- station IDs matching the measurement log,
- bore envelope geometry derived from reviewed station diameters,
- notes naming the measurement log or reviewed design-table export,
- units in inches or a documented unit conversion.

No DXF is created in this lane because the measurement authority is not present
yet.

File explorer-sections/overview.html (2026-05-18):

# 01 · OverviewDidgeridoo bare-bones starter packet

Didgeridoo shop reference

This explorer gathers the didgeridoo starter packet into a reviewable studio surface: stopped-pipe acoustic assumptions, workbook-derived planning rows, BOM and validation gates, bore-profile authority plans, photo documentation needs, and explicit blockers before any build-ready claim.

Readiness boundary

The packet remains L1_packet. It is useful for review and first measurement planning, but fabrication authority is unreleased until measured bore stations, pitch/leak logs, breath-contact safety checks, and reviewed CAD/DXF/design-table evidence exist.

Start here

design.mdA1 bell-flared candidate, stopped-pipe model, source basis, and measurement gates

Open

Validation gate

validation.csvbore, pitch, leak, safety, and CAD authority checks remain open

Open

Authority map

v5-packet-alignment.mdwhy this is a starter slice, not issue #1 sign-off

Open

Round 30

round30-explorer-readiness.mdstash reconciliation and explorer promotion boundary

Open

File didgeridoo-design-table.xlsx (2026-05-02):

Didgeridoo — CNC Design Table
Stopped Pipe: f = v/(4L) · Odd Harmonics (3v/4L, 5v/4L) · 3 Bore Profiles · Source: Didgeridoos.xlsx
DESIGN INPUTS
Speed of Sound (m/s) | 343 | at 20°C
Wall Thickness (in) | 0.5
Mouthpiece Opening (in) | 1.5
KEY & RESONANCE DATA
Note |  | D 1 | Eb 1 | E 1 | F 1 | Gb 1 | G 1 | Ab 1 | A 1 | Bb 1 | B 1 | C 2 | Db 2 | D 2 | Eb 2 | E 2 | F 2 | Gb 2 | G 2 | Ab 2 | A 2 | Bb 2 | B 2 | C 3 | Db 3
Piano Key # |  | 6 | 7 | 8 | 9 | 10 | 11 | 12 | 13 | 14 | 15 | 16 | 17 | 18 | 19 | 20 | 21 | 22 | 23 | 24 | 25 | 26 | 27 | 28 | 29
Fundamental (Hz)
2nd Resonance (3v/4L)
3rd Resonance (5v/4L)
Theoretical Length (in)
CYLINDRICAL BORE
Blank Length (in)
Bore ID (uniform)
Blank OD (turned)
Acoustic Length
End Correction (K1)
CONICAL BORE
Blank Length (in)
Foot End Opening (in) |  | 4.0 | 4.0 | 3.5 | 3.5 | 5.0 | 3.5 | 3.5 | 3.5 | 3.0 | 3.0 | 3.0 | 3.0 | 3.0 | 3.0 | 3.0 | 3.0 | 3.0 | 3.0 | 3.0 | 3.0 | 3.0 | 3.0 | 3.0 | 3.0
Taper Ratio (foot/mouth)
Cone Half-Angle (deg)
Blank OD at Foot
Acoustic Length
End Correction (K1)
BELL BORE
Blank Length (in)
Cone Section Length
Bell Section Length
Bell End Opening (in) |  | 4.0 | 4.0 | 3.5 | 3.5 | 5.0 | 3.5 | 3.5 | 3.5 | 3.0 | 3.0 | 3.0 | 3.0 | 3.0 | 3.0 | 3.0 | 3.0 | 3.0 | 3.0 | 3.0 | 3.0 | 3.0 | 3.0 | 3.0 | 3.0
Blank OD at Bell
Acoustic Length
End Correction (K1)
BILL OF MATERIALS
# | Item | Qty | Size / Notes
1 | Agave stalk (dried) | 1 | 4-6" dia, length per key (see Blank Length). Already hollowed by nature.
2 | OR: Hardwood blank (eucalyptus/mesquite) | 1 | Split, hollow, re-glue method. 4x4 or 6x6 turning blank.
3 | OR: PVC pipe (prototype) | 1 | 1.5" ID Sch 40 PVC, cut to Theoretical Length for quick test.
4 | Beeswax mouthpiece ring | 1 | Shape 1.5" ID opening, warm to fit. Traditional.
5 | Epoxy (if split-blank method) | 4 oz | 2-part slow-cure for re-gluing halves
6 | Sandpaper | assorted | 80/120/220 exterior, 120/220 bore
7 | Finish (exterior) | 8 oz | Tung oil, shellac, or acrylic paint (traditional dot art)
8 | Finish (bore) | 4 oz | Shellac or food-safe oil (seals bore, improves tone)
BUILD METHOD
Method A: Agave Stalk (Natural Bore)
1. Select dried agave stalk, 4-6" dia, naturally hollow
2. Cut to Blank Length for target key (see table above)
3. Clean interior: remove pith with long drill bit or dowel + sandpaper
4. Shape mouthpiece end: sand/file to 1.5" ID opening
5. Tune: test fundamental with tuner, trim from foot end to raise pitch
6. Apply beeswax mouthpiece ring, shape to lips
7. Seal bore with shellac (2 coats, pour-through method)
8. Finish exterior: sand, oil or paint with traditional dot patterns
Method B: Split-Blank (CNC/Lathe)
9. Mill hardwood blank to square cross-section (Blank OD + 1/4")
10. Rip blank in half lengthwise on table saw
11. CNC route: pocket-clear the bore profile in each half
12. For conical: program taper from 1.5" (mouth) to foot-end opening
13. For bell: program 70% cone + 30% flare at foot end
14. Glue halves back together with epoxy, clamp with hose clamps
15. Lathe-turn exterior: round from square, taper or straight per profile
16. Sand exterior on lathe: 80 -> 120 -> 220
17. Shape mouthpiece, apply beeswax ring
18. Tune: test fundamental, adjust by trimming foot end
19. Seal bore + finish exterior
Method C: PVC Prototype (Quick Test)
20. Cut 1.5" Sch 40 PVC to Theoretical Length
21. Test fundamental with tuner -- validate formula before wood build
22. Trim to tune, then use final length to inform wood blank cut
DESIGN NOTES
1. STOPPED PIPE: closed at mouthpiece (lips seal), open at foot. f=v/(4L).
2. Odd harmonics only: 2nd resonance = 3f, 3rd = 5f. This is the "toot" register.
3. Conical bore is louder and richer than cylindrical (better harmonic coupling).
4. Bell bore adds volume projection without changing fundamental significantly.
5. Blank Length = Theoretical + 6" overshoot. Always cut long, tune by trimming foot.
6. Source data: Didgeridoos.xlsx (imported formulas and bore specs).
WOLFRAM CLOUD NOTEBOOK SPEC — DIDGERIDOO
Stopped-pipe drone aerophone of Aboriginal Australia — non-cylindrical bore drives unique 'toot' overtones.
§1 — HISTORY, ETYMOLOGY & ORIGIN
Origin: Aboriginal peoples of northern Australia (Arnhem Land, top end of Northern Territory) — at least 1500 years, possibly much older. Traditional names vary by language: yidaki (Yolngu), mago (Kunwinjku), djalupu, ngaribi, etc.
Didgeridoo' is onomatopoeic, attributed to early-20th-c. European observers — not an Aboriginal word. Many players prefer 'yidaki' as the proper term.
Made traditionally from eucalyptus branches hollowed by termites, then trimmed and sealed with beeswax mouthpiece. Modern variants: agave stalk, bamboo, PVC, glass, ceramic, CNC-routed split-blank wood.
Wolfram items: GeoGraphics over Arnhem Land; Entity["Country","Australia"]; TimelinePlot[{ancient, 1922→first European recording, 1953→Trevor Jones acoustic study, 1990s→worldwide spread}].
§2 — PHYSICS & ACOUSTICS
Stopped pipe (closed at lips): f1 = c/(4·L_eff). Odd harmonic series only for ideal cylinder → 1st overtone at 3·f1 ('toot'), 2nd at 5·f1.
Non-cylindrical bores (cone, bell, irregular eucalyptus) shift overtone ratios — designers tune the toot relative to drone deliberately. Cylindrical: toot ≈ octave+5th. Conical: toot closer to octave. Bell-flared: toot lower than cylindrical.
Vocal-tract coupling: the player's mouth + throat + lungs form a second resonator coupled to the drone. Formant peaks in this tract sweep across the drone spectrum — this is what makes didge timbre dynamic.
Lip reed: like brass instruments. Bernoulli-driven oscillation of lip aperture, frequency-locked to the bore's resonance.
Wolfram functions: NDSolve transmission-line model for non-cylindrical bore; Webster horn equation ∂²p/∂x² + (1/A) (dA/dx) ∂p/∂x = (1/c²) ∂²p/∂t²; Periodogram + Spectrogram for circular-breathing sustain analysis.
§3 — GEOMETRY & DESIGN MODEL
Three bore profiles in this sheet: cylindrical, conical, bell-flared. Parameterize as A(x) = π·r(x)². r(x) = r_mouthpiece + (r_bell−r_mouthpiece)·(x/L)^p where p∈{0=step, 1=cone, 2=bell}.
Length sets drone: L = c/(4·f1) − end correction. Typical: D2 ≈ 60", C2 ≈ 67", but eucalyptus pieces drive their own length (build-from-found-stick philosophy).
Wolfram items: ParametricPlot3D bore as surface of revolution; RegionPlot3D for cavity volume; Manipulate for L, r_in, r_out, profile exponent p, mouthpiece bore.
§4 — MATERIAL & CORRECTION FACTORS
Eucalyptus: ρ ≈ 600–900 kg/m³ depending on species; high internal damping vs. metal/PVC → darker, woodier timbre.
Beeswax mouthpiece: ~30–40 mm bore, sealed onto end. Sets effective lip impedance — softer wax = more responsive.
End correction at bell: ΔL ≈ 0.6·r_bell. Larger bell flare → stronger formant peaks.
Temperature/humidity: c shifts ~0.6 m/s per °C; player's warm breath inside the bore offsets ambient — a cold didge plays sharp on first breath, settles flat after warming.
§5 — BOM HOOK & MAP
SemanticImport["Flutes-AI.xlsx","Didgeridoo"] → BOM rows; group by build method (split-blank, agave, PVC).
Map: GeoGraphics Arnhem Land + insets for major regional traditions (Yolngu, Kunwinjku, Bininj). Cite Aboriginal origin prominently.
§6 — ANIMATED DIAGRAMS
Bore profile animation: Manipulate exponent p ∈ {0,1,2,3} → see bore shape morph cylinder ↔ cone ↔ bell, with overlay of 1st/3rd/5th resonance.
Standing-wave Animate: pressure node at bell, anti-node at lips, for fundamental + toot + 5th resonance.
Vocal-tract overlay: side-by-side Plot of bore impedance + tract impedance, sweep tract formants live with Manipulate.
§7 — EXECUTABLE CELL SKETCHES
lDidge[f_,r_]:=343/(4 f) - 0.6 r (* m, Hz, m *)
boreA[x_, L_, rIn_, rOut_, p_]:=π (rIn + (rOut-rIn) (x/L)^p)^2
websterModes[A_,L_,c_]:= NDEigensystem[{D[A[x] D[p[x],x],x] + (ω^2/c^2) A[x] p[x], (* BCs *)}, p, {x,0,L}, 5]
validate: AudioRecord drone, Spectrogram, locate fundamental + toot, compare ratio to predicted from bore profile.
§8 — DEPLOYMENT
CloudDeploy bore-profile-to-frequency calculator; APIFunction that accepts profile points + L → returns predicted f1 and overtone series.
Wolfram functions: CloudDeploy, APIFunction, FormFunction, AudioCapture, Spectrogram, NonlinearModelFit, Export[ ,"CDF"|"MP4"].
WOLFRAM EXPLORATIONS — DIDGERIDOO
Curated from the wolfram-notebooks-roadmap brainstorm — pick a row, file an issue, build the notebook.
Roadmap-inspired notebook ideas tailored to this sheet:
• Conical Bore Impedance (Transfer Matrix) — Transfer-matrix method for non-cylindrical bore; predict toot frequency vs profile exponent p.
• Cross-Section Sweep Animator — Plane sweeps through 3D bore model — visceral way to see how cylinder→cone→bell changes the resonance ladder.
• Vocal-Tract Coupled Synth — Player tract + bore impedance; manipulate tongue position → formants sweep across drone spectrum (audible morph).
• Termite-Bore Irregular Shape Solver — Webster horn equation on an arbitrary measured r(z) profile; predict drone + toot from any blank.
• Cultural Map: Arnhem Land Yidaki Traditions — GeoGraphics Yolngu / Kunwinjku regions; cite proper names; respectful attribution layer.

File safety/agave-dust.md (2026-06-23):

# Agave Dust Safety Annex — Raphides & PPE

> **Canonical source.** This is the single authoritative safety reference for agave (and yucca) machining dust in this project. Do **not** duplicate this content elsewhere. Other documents (makerspace A7, build guides, stock-prep SOPs) must **link** to this file, not copy it.

---

## 1. The Hazard: Calcium-Oxalate Raphides

Agave and yucca plants store calcium oxalate in needle-shaped crystals called **raphides**, embedded in the cell walls throughout the stalk, skin, and pith. Raphides are typically 100–400 µm long — invisible to the naked eye — and are released as airborne dust when agave or yucca is:

- Cross-cut with a saw
- Bored, gouged, or drilled
- Sanded or rasped
- Dried-split (splitting also releases fibre dust)

**Why they matter:**

| Exposure route | Effect |
|---|---|
| Skin contact (fine dust) | Contact dermatitis: itching, redness, localised irritation — sometimes delayed by 20–60 min |
| Eye contact | Mechanical irritation, conjunctivitis; crystals can scratch the cornea |
| Inhalation | Upper-respiratory irritation, throat irritation; repeated exposure can cause persistent airway sensitivity |
| Ingestion (rare, via hand-to-mouth) | Oral and GI irritation |

Raphide hazard is distinct from wood dust carcinogenicity — it is a mechanical/chemical irritant, not a known carcinogen. However, it is a real and unpleasant hazard that must be controlled.

Yucca has a comparable raphide load to agave; treat all yucca dust as equivalent.

---

## 2. Required PPE

Wear all three during any agave or yucca machining (cutting, boring, sanding, splitting):

| PPE item | Minimum spec | Notes |
|---|---|---|
| **Respirator** | N95 particulate respirator (minimum); P100 half-mask preferred for prolonged sanding or gouging | Disposable N95 is adequate for short-duration cuts; P100 for sessions > 15 min or heavy material removal |
| **Eye protection** | Safety glasses with side shields (minimum); full goggles preferred for overhead or power-tool work | Standard prescription glasses are **not** adequate — no side protection |
| **Skin coverage** | Long sleeves; gloves for prolonged hand contact | Nitrile or latex gloves for gouging sessions; bare hands on smooth finished surfaces are generally fine |

**Do not:** work without the respirator even for a "quick" cut. A single cross-cut releases a measurable raphide cloud.

---

## 3. Dust Control Measures

In addition to PPE, use at least one active dust-control method:

| Method | Effectiveness | Notes |
|---|---|---|
| Shop vacuum with HEPA filter at the cut/bore point | High — captures dust at source | Most effective; hold the vacuum nozzle within 2 in of the work |
| Wet method: mist the work surface before cutting/sanding | Moderate — suppresses airborne fraction | Useful for coarse cutting; do not soak (softens the stalk) |
| Outdoor or well-ventilated area | Low alone — dilution only | Supplement with one of the above; insufficient as a standalone control |
| Dust mask (non-rated cloth mask) | Not adequate | Not a substitute for a rated N95 or P100 |

---

## 4. After-Work Hygiene

1. **Wash hands and forearms** with soap and water before touching your face.
2. **Change or brush off clothing** before moving to a non-dusty area — raphides cling to fabric and can cause delayed contact irritation.
3. **Clean the work area** with a HEPA vacuum (not a leaf blower or compressed air — that re-aerosolises the dust).
4. If skin irritation occurs: rinse the area with cool water for 5–10 min. Antihistamine cream can reduce itching. Seek medical attention if irritation is severe or involves the eyes.

---

## 5. Quick Pre-Work Checklist

```
[ ] Respirator — N95 or P100, fitted and sealed
[ ] Safety glasses or goggles — side shields present
[ ] Long sleeves (and gloves if extended gouging session)
[ ] Dust-control active — HEPA vac at source, or wet method, or outdoors + vac
[ ] Work area clear of unprotected bystanders
```

---

## 6. Linking from Other Documents

All build guides, stock-prep SOPs, and makerspace station notes (e.g., A7) that involve agave or yucca machining should add a single cross-reference line like:

```
> Dust safety: see `safety/agave-dust.md` for raphide hazard and PPE requirements.
```

Do not copy the PPE table or hazard description into those documents — link here instead. This file is the single source; updates propagate automatically via the link.

---

## References

- Kingsbury, J.M. (1964). *Poisonous Plants of the United States and Canada.* Calcium oxalate raphide distribution in Agavaceae.
- NIOSH Pocket Guide to Chemical Hazards — Calcium Oxalate (for general oxalate dust context).
- Agave nectar / sisal industry occupational health data — raphide dermatitis is a well-documented occupational hazard in sisal processing.

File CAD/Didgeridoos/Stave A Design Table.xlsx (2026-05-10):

Design Table for: Stave A
 | Theta@Sketch1 | t@Sketch1 | R@Sketch1 | ISWA@Sketch1 | D1@Cut To Length
01. Stave A - C3 | 60.00 | 0.75 | 0.62 | 0.62 | 27.00
02. Stave A - B2 | 60.00 | 0.75 | 0.62 | 0.62 | 28.58
03. Stave A - A2# | 60.00 | 0.75 | 0.62 | 0.62 | 30.23
04. Stave A - A2 | 60.00 | 0.75 | 0.62 | 0.62 | 32.03
05. Stave A - G2# | 60.00 | 0.75 | 0.75 | 0.75 | 33.99
06. Stave A - G2 | 60.00 | 0.75 | 0.75 | 0.75 | 35.98
07. Stave A - F2# | 60.00 | 0.75 | 0.75 | 0.75 | 38.10
08. Stave A - F2 | 60.00 | 0.75 | 0.75 | 0.75 | 40.33
09. Stave A - E2 | 60.00 | 0.75 | 0.88 | 0.87 | 42.78
10. Stave A - D2# | 60.00 | 0.75 | 0.88 | 0.87 | 45.30
11. Stave A - D2 | 60.00 | 0.75 | 0.88 | 0.87 | 47.95
12. Stave A - C2# | 60.00 | 0.75 | 1.00 | 1.00 | 50.85
13. Stave A - C2 | 60.00 | 0.75 | 1.00 | 1.00 | 53.85
14. Stave A - B1 | 60.00 | 0.75 | 1.00 | 1.00 | 57.00
15. Stave A - A1# | 60.00 | 0.75 | 1.12 | 1.12 | 60.44
16. Stave A - A1 | 60.00 | 0.75 | 1.12 | 1.12 | 63.99
17. Stave A - G1# | 60.00 | 0.75 | 1.12 | 1.12 | 67.76
18. Stave A - G1 | 60.00 | 0.75 | 1.12 | 1.12 | 71.74
19. Stave A - F1# | 60.00 | 0.75 | 1.12 | 1.12 | 75.97
20. Stave A - F1 | 60.00 | 0.75 | 1.25 | 1.25 | 80.51
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

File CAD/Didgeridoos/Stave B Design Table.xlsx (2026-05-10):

Design Table for: Stave B Temp 2
 | Crosscut Angle@Sketch1 | Crosscut Angle 2@Sketch1 | BISW@Sketch1 | Cut To Length@Sketch1 | D1@Boss-Extrude1 | Dado Depth@Sketch3 | Degree of Flare (plus ninety)@Sketch3 | D3@Boss-Extrude1
Default | 95.443 | 95.443 | 1.25 | 27.21 | 0.75 | 0.375 | 99.5 | 29.547
01. Stave B - C3 | 95.44329509 | 95.44329509 | 0.88 | 9.12 | 0.75 | 0.375 | 99.50 | 29.54735891
02. Stave B - B2 | 95.44329509 | 95.44329509 | 0.91 | 9.66 | 0.75 | 0.375 | 99.50 | 29.54735891
03. Stave B - A2# | 95.44329509 | 95.44329509 | 0.94 | 10.22 | 0.75 | 0.375 | 99.50 | 29.54735891
04. Stave B - A2 | 95.44329509 | 95.44329509 | 0.98 | 10.83 | 0.75 | 0.375 | 99.50 | 29.54735891
05. Stave B - G2# | 95.44329509 | 95.44329509 | 1.09 | 11.49 | 0.75 | 0.375 | 99.50 | 29.54735891
06. Stave B - G2 | 95.44329509 | 95.44329509 | 1.13 | 12.16 | 0.75 | 0.375 | 99.50 | 29.54735891
07. Stave B - F2# | 95.44329509 | 95.44329509 | 1.17 | 12.88 | 0.75 | 0.375 | 99.50 | 29.54735891
08. Stave B - F2 | 95.44329509 | 95.44329509 | 1.22 | 13.63 | 0.75 | 0.375 | 99.50 | 29.54735891
09. Stave B - E2 | 95.44329509 | 95.44329509 | 1.33 | 14.46 | 0.75 | 0.375 | 99.50 | 29.54735891
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

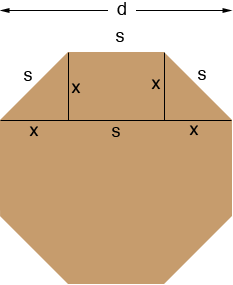
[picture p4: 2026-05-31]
octogone dimensions solver.gif

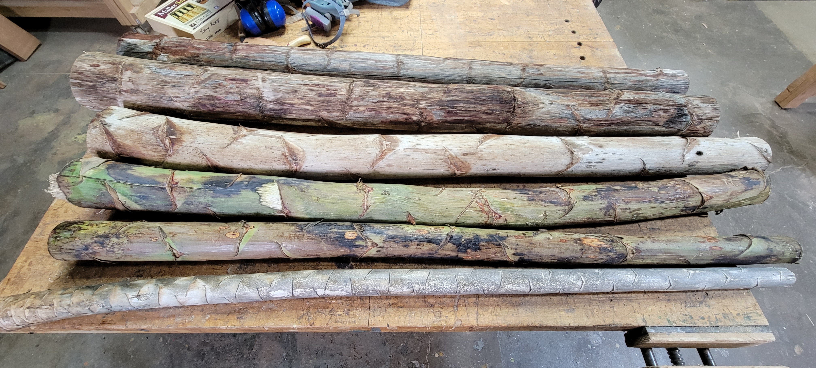
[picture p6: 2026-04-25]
images/2022-02-12 13.09.07.jpg

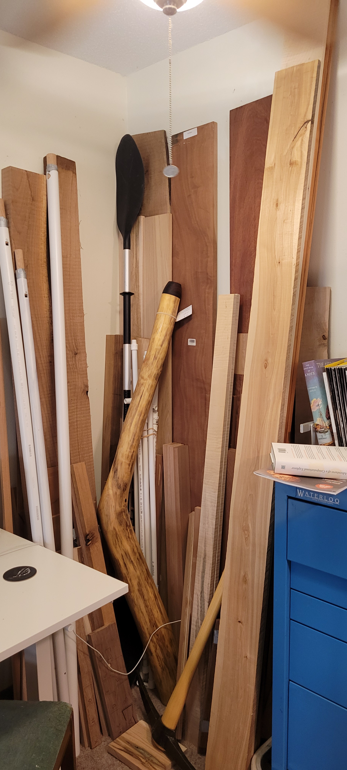
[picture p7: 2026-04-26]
images/2021-08-14 10.14.01.jpg

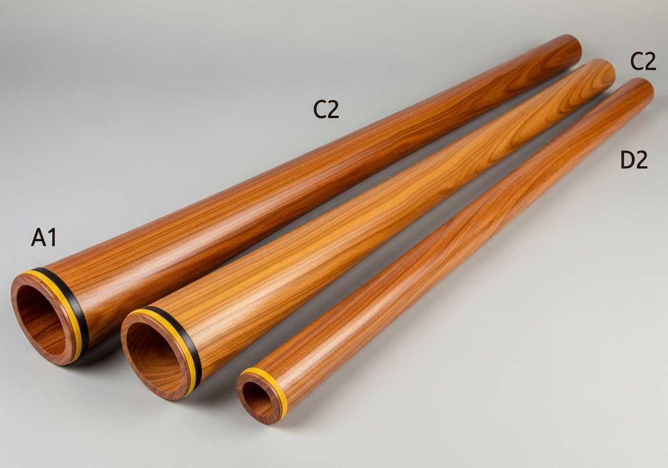
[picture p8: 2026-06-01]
images/family-group.png

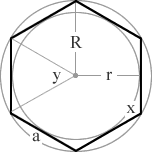
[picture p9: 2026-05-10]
polygon_06_hexagon.gif

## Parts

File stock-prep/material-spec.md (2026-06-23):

# Agave & Yucca — Material-Selection Spec & Grading Rubric

Use this rubric at harvest or purchase time (A6 log entry) to decide whether a stalk is instrument-grade.  
Grade every stalk before cutting. Record pass/reject + notes in the A6 log.

---

## 1. Dryness

| Check | Pass | Reject |
|---|---|---|
| Weight | Noticeably light for its size — dried stalk feels hollow | Heavy, damp, or noticeably dense |
| Surface | Papery skin, hard outer cortex, no tacky/green zones | Soft or spongy outer cortex; any green colouration |
| Knuckle-tap | Clear ring or hollow knock (see `cure-check.md`) | Dull thud, or muffled — indicates residual moisture |
| Crack pattern | Fine longitudinal cracks acceptable — sign of good drying | Cross-grain or spiral cracks through the wall |

**Reject trigger:** Any single fail in the Reject column = reject the stalk or flag for extended drying.

---

## 2. Wall Thickness

Measure with calipers or a ruler at the cut end and at mid-stalk.

| Measurement | Pass | Reject / Conditional |
|---|---|---|
| Wall thickness (agave) | **1/4 in – 1/2 in** (6–13 mm) | < 1/4 in → too fragile; > 1/2 in → bore too small to gouge reliably |
| Wall thickness (yucca) | **1/4 in – 1/2 in** (same range after pith removal) | Same thresholds; measure post-pith gouge estimate |
| Uniformity around circumference | ≤ 1/8 in variation side to side | > 1/8 in variation → asymmetric bore; mark as conditional |

**Note:** Yucca wall is measured as outer diameter minus estimated pith diameter. If pith is off-centre, the usable wall may be uneven — apply the uniformity check.

---

## 3. Taper

Taper drives backpressure and acoustics. Measure outer diameter at the base end and the upper (mouthpiece) end.

| Characteristic | Pass | Conditional | Reject |
|---|---|---|---|
| Taper direction | Base wider than mouthpiece end (natural bore taper) | Uniform cylinder (no taper) — requires acoustic modelling | Reverse taper (mouthpiece wider than base) |
| Taper rate | Gradual, ≤ 0.5 in diameter change per foot of length | Abrupt shoulder or step > 0.5 in over < 6 in | Kink, crush, or collapsed zone anywhere along the stalk |
| Bell zone | Natural flare or gentle widening at base end | Absent (cylindrical base) — acceptable for rainstick/flute variants | Cracked flare that compromises structural integrity |

**Conditional** stalks may be used for non-backpressure instruments (rainstick, percussion blank) even if they fail the didgeridoo taper spec.

---

## 4. Structural Integrity

| Check | Pass | Reject |
|---|---|---|
| Surface rot | None; dried cortex firm everywhere | Soft spots, black zones, fungal patches |
| Insect damage | Minor surface galleries acceptable | Through-wall galleries; hollow chambers from insect activity |
| Splits | Fine shrinkage cracks (< 1/8 in wide, longitudinal only) | Open splits running through the wall or cross-grain |
| Residue | Light natural wax or surface oxidation acceptable | Pitch, sap, or adhesive residue blocking bore access |

---

## 5. Minimum Useful Length

| Instrument | Minimum stalk length |
|---|---|
| Didgeridoo (A1/Bb1 range) | 55 in (~140 cm) |
| Rainstick | 24 in (60 cm) |
| NA-flute blank | 18 in (45 cm) |
| Trim / test piece | Any length |

Stalks shorter than 55 in that pass all other criteria: log as rainstick/flute candidates.

---

## 6. Quick Field Checklist (A6 Log Entry)

```
Stalk ID: ___________   Date: ___________   Species: [ ] agave  [ ] yucca

DRYNESS
  [ ] Weight — light for size
  [ ] Surface — hard, papery, no green
  [ ] Tap — clear ring (see cure-check.md)
  [ ] Crack pattern — longitudinal only

WALL (record measurements)
  Cut-end wall: ______ in    Mid-stalk wall: ______ in
  [ ] Both in 1/4–1/2 in range
  [ ] Uniformity ≤ 1/8 in variation

TAPER
  Base OD: ______ in    Mouthpiece OD: ______ in
  Taper rate: ______ in/ft
  [ ] Gradual taper, base wider than mouthpiece end
  [ ] No kinks or collapsed zones

STRUCTURAL
  [ ] No rot or fungal zones
  [ ] No through-wall insect damage
  [ ] No open splits
  [ ] Bore/surface free of blocking residue

Length: ______ in

VERDICT:  [ ] PASS — instrument grade  [ ] CONDITIONAL — rainstick/flute only  [ ] REJECT

Notes:
```

---

## Cross-References

- Cure verification test: `stock-prep/cure-check.md`
- Multi-cut zone planning once passed: `stock-prep/cut-plan.md`
- Bore prep (split-and-glue): `stock-prep/bore-prep.md`
- Safety (agave dust / raphides): `safety/agave-dust.md`

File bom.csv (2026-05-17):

item_id | item | qty | spec | status | source_status | evidence | notes
BOM-001 | Prototype tube | 1 | 1.5 in nominal ID PVC or comparable test tube | optional | unverified_until_purchase | didgeridoo-design-table.xlsx row 46 | Fastest length and mouthpiece validation path; not final aesthetic material.
BOM-002 | Dried agave stalk | 1 | 4-6 in diameter and long enough for selected blank | optional | unverified_until_purchase | didgeridoo-design-table.xlsx row 44 | Use only if the natural bore can be measured and cleaned safely.
BOM-003 | Hardwood split blank | 1 | blank large enough for selected OD and length | optional | unverified_until_purchase | didgeridoo-design-table.xlsx row 45 | Candidate for CNC-routed halves after geometry is validated.
BOM-004 | Beeswax mouthpiece ring | 1 | shape to 1.5 in opening | required_for_play_test | unverified_until_purchase | didgeridoo-design-table.xlsx row 47 | Removable/testable mouthpiece before permanent ergonomic decisions.
BOM-005 | Slow-cure epoxy | 4 oz | breath-adjacent-safe only after cure and review | conditional | unverified_until_purchase | didgeridoo-design-table.xlsx row 48 | For split-blank glue-up; safety and cure state must be documented.
BOM-006 | Sandpaper | assorted | 80 120 220 exterior and bore grits | required | unverified_until_purchase | didgeridoo-design-table.xlsx row 49 | Avoid loose dust in bore before play testing.
BOM-007 | Bore sealant | 4 oz | shellac or other breath-contact-reviewed finish | required | unverified_until_purchase | didgeridoo-design-table.xlsx row 51 | Do not use until finish safety gate is documented.
BOM-008 | Exterior finish | 8 oz | tung oil shellac paint or other exterior finish | optional | unverified_until_purchase | didgeridoo-design-table.xlsx row 50 | Exterior-only unless separately cleared for bore contact.
BOM-009 | Digital tuner or spectrum app | 1 | records fundamental and toot frequencies | required | tool_required | validation-loop.csv | Measurement tool rather than consumed material.
BOM-010 | Bore measuring tools | 1 set | calipers dowels gauge balls or bore scope | required | tool_required | validation-loop.csv | Needed before any CAD/DXF authority claim.

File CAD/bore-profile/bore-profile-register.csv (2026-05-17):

artifact_id | path | profile | candidate_id | artifact_kind | authority_level | dimension_claim | source_basis | next_action | notes
BPR-001 | CAD/bore-profile/bore-profile-register.csv | all | all | register | planning_record | none | assignment and instrument-maker visual authority rules | keep updated as CAD is added | This register is not fabrication geometry.
BPR-002 | CAD/bore-profile/v5-a1-bell-stations.csv | bell | DID-V5-A1-BELL-P0 | measurement_template | future_authority_after_measurement | measurement_required | didgeridoo-design-table.xlsx rows 34-40 | create measured station table | Future station CSV should become the first authority candidate.
BPR-003 | CAD/bore-profile/v5-a1-bell.dxf | bell | DID-V5-A1-BELL-P0 | dxf | not_created | none | none | derive only from reviewed station table | No DXF exists yet; do not infer toolpaths from prose.
BPR-004 | CAD/bore-profile/v5-c2-conical-stations.csv | conical | DID-V5-C2-CONICAL-P0 | measurement_template | comparison_only | measurement_required | didgeridoo-design-table.xlsx rows 24-31 | defer until A1 validation | Comparison profile only.
BPR-005 | CAD/bore-profile/v5-d2-cylindrical-stations.csv | cylindrical | DID-V5-D2-CYL-P0 | measurement_template | comparison_only | measurement_required | didgeridoo-design-table.xlsx rows 17-22 | defer until A1 validation | Straight-bore reference for formula checks.

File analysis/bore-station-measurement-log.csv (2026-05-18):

instrument_id | blank_id | operator | date_utc | source_artifact | profile_model | station_id | station_pct | axial_position_in | inner_diameter_major_in | inner_diameter_minor_in | wall_thickness_in | circumference_in | measurement_tool | measurement_repeat_count | temperature_c | humidity_pct | photo_id | authority_status | notes
DID-B5 |  |  |  |  | unselected | BS-000 | 0 |  |  |  |  |  |  |  |  |  |  |  | unmeasured | Mouthpiece datum; do not infer from photo.
DID-B5 |  |  |  |  | unselected | BS-005 | 5 |  |  |  |  |  |  |  |  |  |  |  | unmeasured | Near-mouthpiece bore station.
DID-B5 |  |  |  |  | unselected | BS-010 | 10 |  |  |  |  |  |  |  |  |  |  |  | unmeasured | Early bore transition station.
DID-B5 |  |  |  |  | unselected | BS-020 | 20 |  |  |  |  |  |  |  |  |  |  |  | unmeasured | Upper bore station.
DID-B5 |  |  |  |  | unselected | BS-030 | 30 |  |  |  |  |  |  |  |  |  |  |  | unmeasured | Upper-middle bore station.
DID-B5 |  |  |  |  | unselected | BS-040 | 40 |  |  |  |  |  |  |  |  |  |  |  | unmeasured | Mid-bore station.
DID-B5 |  |  |  |  | unselected | BS-050 | 50 |  |  |  |  |  |  |  |  |  |  |  | unmeasured | Center bore station.
DID-B5 |  |  |  |  | unselected | BS-060 | 60 |  |  |  |  |  |  |  |  |  |  |  | unmeasured | Lower-middle bore station.
DID-B5 |  |  |  |  | unselected | BS-070 | 70 |  |  |  |  |  |  |  |  |  |  |  | unmeasured | Lower bore or bell-transition station.
DID-B5 |  |  |  |  | unselected | BS-080 | 80 |  |  |  |  |  |  |  |  |  |  |  | unmeasured | Late bore station.
DID-B5 |  |  |  |  | unselected | BS-090 | 90 |  |  |  |  |  |  |  |  |  |  |  | unmeasured | Pre-foot flare station.
DID-B5 |  |  |  |  | unselected | BS-100 | 100 |  |  |  |  |  |  |  |  |  |  |  | unmeasured | Open foot datum.

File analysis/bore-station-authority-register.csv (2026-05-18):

authority_id | artifact | path | status | can_drive_fabrication | requires_before_use | notes
AUTH-B5-001 | 2013 notebook photo | images/20260425_122104.jpg | reference_evidence | false | Transcribe and review source table | Primary historical evidence but not station-by-station bore measurement.
AUTH-B5-002 | CNC design workbook | didgeridoo-design-table.xlsx | planning_evidence | false | Review formulas and export design table rows | Contains stopped-pipe and profile planning formulas; not a measured bore log.
AUTH-B5-003 | Bore station map | analysis/bore-station-station-map.csv | measurement_template | false | Choose blank length and convert normalized stations | Defines capture stations only.
AUTH-B5-004 | Bore station log | analysis/bore-station-measurement-log.csv | empty_template | false | Populate with measured positive diameters and review | Becomes a dimensional source only after measurement and review.
AUTH-B5-005 | OpenSCAD starter | CAD/bore-profile/didgeridoo-bore-starter.scad | starter | false | Populate from AUTH-B5-004 or reviewed design table | May render a station plate now; bore envelope is blocked until dimensions exist.
AUTH-B5-006 | DXF authority plan | drawings/didgeridoo-bore-dxf-authority-plan.md | plan | false | Export a DXF only after AUTH-B5-004 is reviewed | DXF path is planned; no DXF fabrication geometry is claimed in this lane.

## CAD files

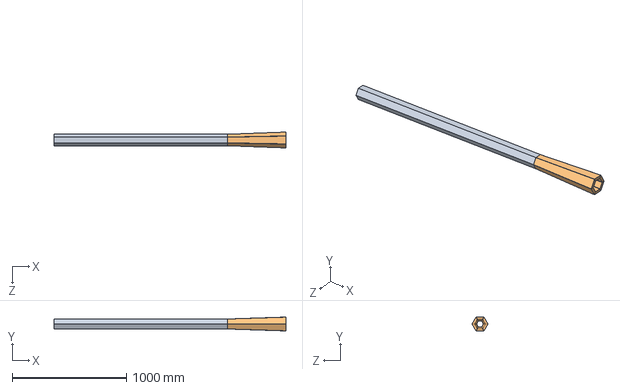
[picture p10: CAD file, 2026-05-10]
CAD/Didgeridoos/Assemblies/Stave A and B Assembly.SLDASM
2026.7 x 121.3 x 139.1 mm
Stave A Temp x 6
Stave B Temp x 6

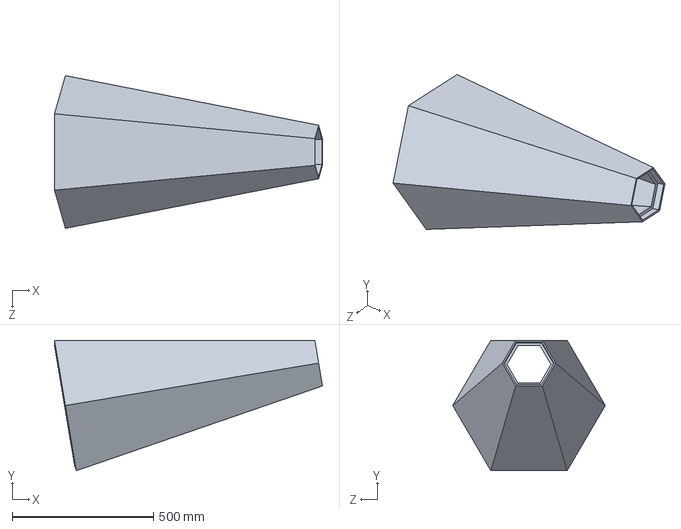
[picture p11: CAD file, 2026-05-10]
CAD/Didgeridoos/Assemblies/Temp B 2.SLDASM
947.6 x 461.2 x 540.0 mm
Stave B Temp 2 x 6

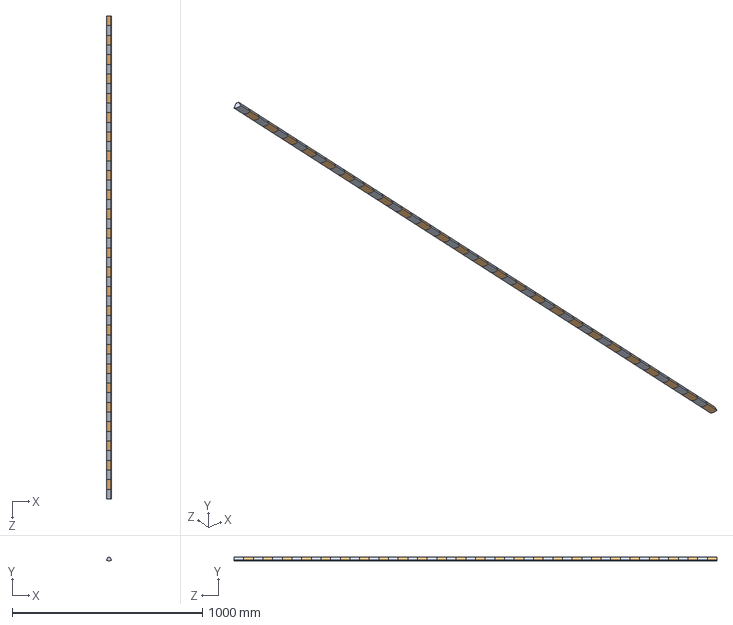
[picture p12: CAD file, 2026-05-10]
CAD/Didgeridoos/Bi-Colored Assembly 2.SLDASM
28.2 x 19.1 x 2540.0 mm
Small Block x 25
Small Block - Ash x 25

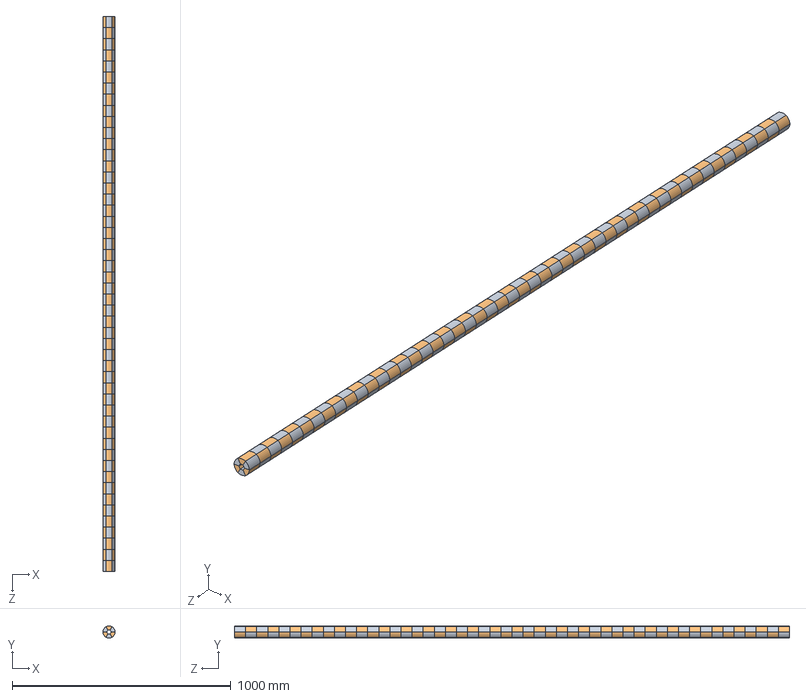
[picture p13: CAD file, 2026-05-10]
CAD/Didgeridoos/All Together.SLDASM
56.5 x 55.0 x 2540.0 mm
Small Block - Ash x 150
Small Block x 150

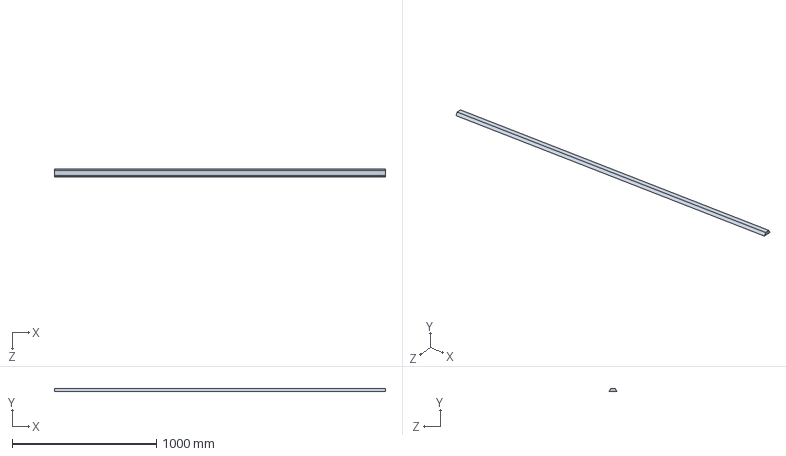
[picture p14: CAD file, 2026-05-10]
CAD/Didgeridoos/Parts/Stave A - Didgeridoo.SLDPRT
2293.4 x 19.1 x 53.7 mm

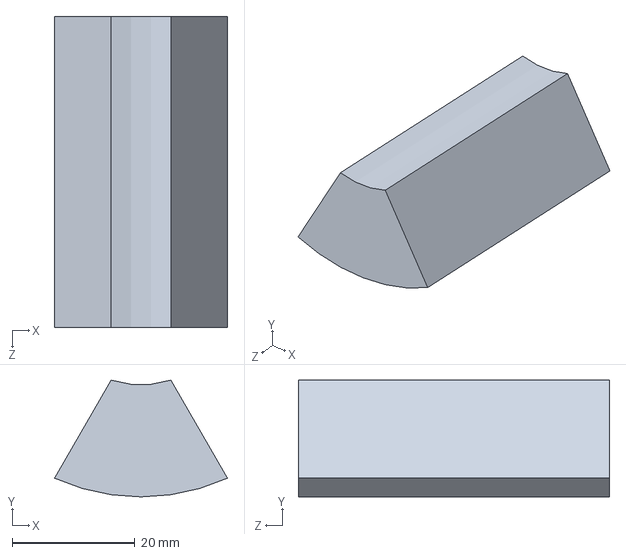
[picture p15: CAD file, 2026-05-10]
CAD/Didgeridoos/Small Block.SLDPRT
28.2 x 19.1 x 50.8 mm

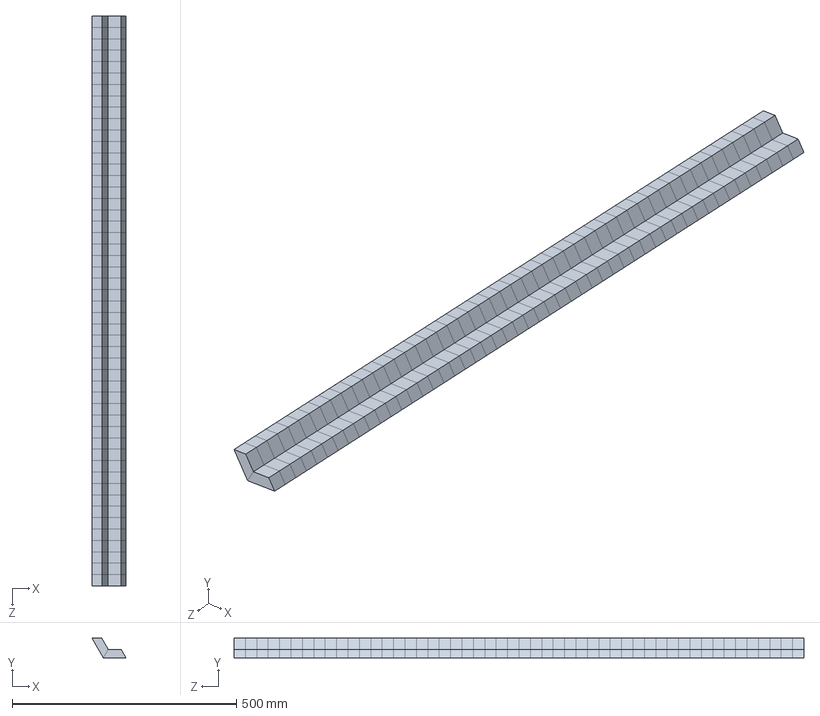
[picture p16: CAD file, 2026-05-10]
CAD/Didgeridoos/All Together Test.SLDPRT
76.2 x 44.0 x 1270.0 mm

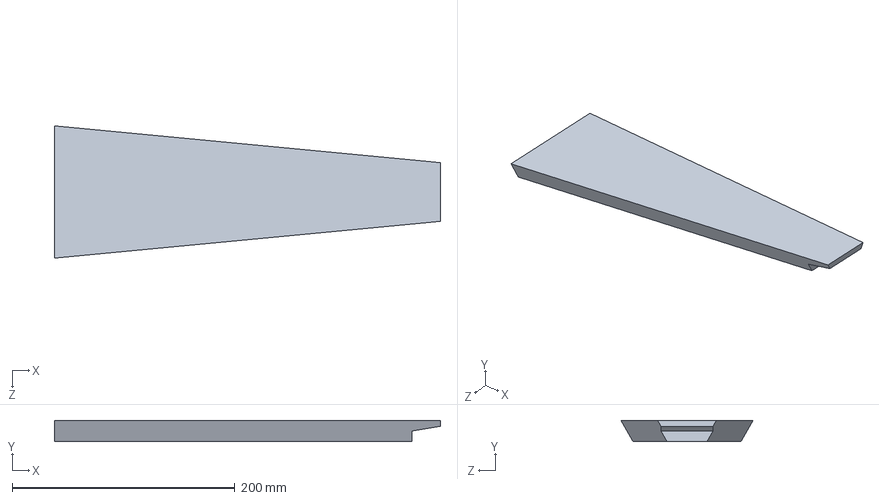
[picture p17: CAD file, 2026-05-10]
CAD/Didgeridoos/Parts/Stave B - Didgeridoo.SLDPRT
346.2 x 19.1 x 118.6 mm

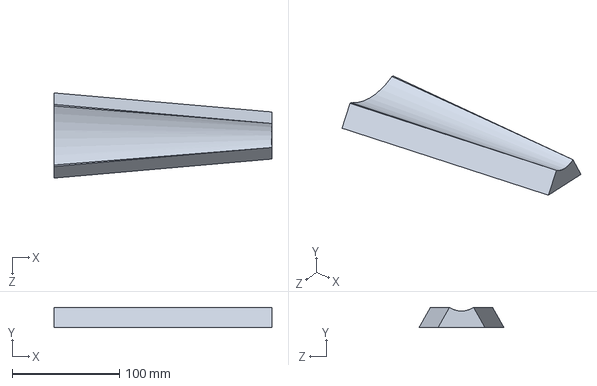
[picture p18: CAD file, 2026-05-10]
CAD/Didgeridoos/Assemblies/Stave B Temp 3.SLDPRT
203.2 x 18.9 x 79.4 mm

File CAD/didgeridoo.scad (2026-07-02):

// Didgeridoo bore-flare envelope master.
// tonykoop/didgeridoo — CAD/didgeridoo.scad
//
// AUTHORITY: pending_measurement. NOT fabrication authority. This file
// renders a candidate bore-flare ENVELOPE for shop review only; it does not
// control cut geometry until every interior station is measured and
// reviewed (see analysis/bore-station-measurement-log.csv,
// analysis/bore-station-authority-register.csv AUTH-B5-004/005).
//
// Source of truth for every numeric parameter below:
//   - family-spec.csv rows DID-V5-A1-BELL-P0 / DID-V5-C2-CONICAL-P0 /
//     DID-V5-D2-CYL-P0 (mouthpiece_bore_id_in, foot_bell_id_in,
//     starter_blank_length_in, theoretical_quarter_wave_length_in,
//     target_hz), themselves derived from didgeridoo-design-table.xlsx
//     "Didgeridoo" worksheet rows 10-40 (see design.md "Source Basis").
//   - wall_thickness_in: design.md "Source Basis" — "Wall thickness input:
//     0.50 in" (workbook input). CAD/didgeridoo-openscad-authority-plan.md
//     still flags wall thickness as measurement-required for the as-built
//     prototype, so this stays a planning assumption, not a confirmed
//     as-built value.
//   - station grid (0/5/10/20/.../100 %): analysis/bore-station-station-map.csv.
//   - interior station diameters: analysis/bore-station-measurement-log.csv
//     — currently EVERY row is "unmeasured". This master therefore has no
//     real interior-profile data to draw from for any family.
//
// Governing shape, by family-spec.csv `profile` column:
//   - cylindrical: mouth ID == foot/bell ID BY DEFINITION -> every interior
//     station equals the design-table mouth ID exactly. No shape assumption.
//   - conical: straight-sided cone BY DEFINITION -> every interior station
//     is the exact linear interpolation between the design-table mouth ID
//     and foot/bell ID. No shape assumption (this is what "conical" means).
//   - bell: NO interior-taper formula exists anywhere in this repo.
//     design.md only says "gradual expansion from mouth opening toward
//     bell." Only the two endpoints (mouth ID, bell ID) and the overall
//     blank length are design-table values. When bell_show_assumption_curve
//     is true (default, so this file always renders something for the shop
//     to look at) the interior stations are filled by
//     bell_flare_exponent_assumption below — an ASSUMPTION, clearly labeled,
//     not measured or reviewed. When false, interior bell stations fall back
//     to the TBD sentinel and the module renders a flat station-check plate
//     instead of a solid, exactly like CAD/bore-profile/didgeridoo-bore-starter.scad.
//
// fabrication_mode stays false. measurement_reviewed stays false until a
// real measurement pass against analysis/bore-station-measurement-log.csv is
// recorded and reviewed — flipping fabrication_mode alone can never make
// this master fabrication authority.

inch = 25.4;

// ---- top-level switches -----------------------------------------------
profile = "bell"; // "bell" | "conical" | "cylindrical" — family-spec.csv row to render
fabrication_mode = false; // never true without a reviewed measurement pass
measurement_reviewed = false; // set true only after a reviewed pass over
                               // analysis/bore-station-measurement-log.csv
bell_show_assumption_curve = true; // true: draw ONE labeled candidate bell
                                    // flare curve (assumption, not authority)

// ---- design-table-derived family rows (family-spec.csv) ----------------
// [key, mouth_bore_id_in, foot_bell_id_in, starter_blank_length_in,
//  quarter_wave_length_in, target_hz, family_spec_row_id]
family = [
  ["bell",        1.50, 3.50, 67.50, 61.38, 55.00, "DID-V5-A1-BELL-P0"],
  ["conical",     1.50, 3.00, 57.75, 51.62, 65.41, "DID-V5-C2-CONICAL-P0"],
  ["cylindrical", 1.50, 1.50, 52.00, 45.98, 73.42, "DID-V5-D2-CYL-P0"],
];

wall_thickness_in = 0.50; // design.md Source Basis; unreviewed as-built value

// ---- bore-station grid (analysis/bore-station-station-map.csv) ---------
station_pct = [0, 5, 10, 20, 30, 40, 50, 60, 70, 80, 90, 100];
station_labels = [
  "BS-000", "BS-005", "BS-010", "BS-020", "BS-030", "BS-040",
  "BS-050", "BS-060", "BS-070", "BS-080", "BS-090", "BS-100",
];

// ASSUMPTION — not from design table, not from any measurement. No
// interior-taper formula exists for the bell family anywhere in this repo.
// This exponent just picks one illustrative, monotonic, mouth-slow /
// bell-fast flare shape for shop-review visualization. Replace with real
// analysis/bore-station-measurement-log.csv values once measured + reviewed.
bell_flare_exponent_assumption = 2.2;

function family_row(key) =
  family[0][0] == key ? family[0] :
  family[1][0] == key ? family[1] :
  family[2][0] == key ? family[2] :
  family[0]; // fall back to "bell" rather than crash on a typo

row = family_row(profile);
mouth_id_in = row[1];
bell_id_in = row[2];
length_in = row[3];
quarter_wave_in = row[4];
target_hz = row[5];
row_id = row[6];

// diameter_at(t_pct): honest interior-diameter model per family, in inches.
// Returns -1 (TBD sentinel, same convention as didgeridoo-bore-starter.scad)
// wherever no real value exists.
function diameter_at(t_pct) =
  profile == "cylindrical" ? mouth_id_in :
  profile == "conical" ? mouth_id_in + (bell_id_in - mouth_id_in) * (t_pct / 100) :
  // profile == "bell"
  (bell_show_assumption_curve
    ? mouth_id_in + (bell_id_in - mouth_id_in) * pow(t_pct / 100, bell_flare_exponent_assumption)
    : (t_pct == 0 || t_pct == 100 ? (t_pct == 0 ? mouth_id_in : bell_id_in) : -1));

interior_diameter_in = [for (t = station_pct) diameter_at(t)];

function has_all_stations(v) = min(v) >= 0;

if (fabrication_mode) {
  assert(
    measurement_reviewed,
    "NO FABRICATION: pending_measurement. Populate and review analysis/bore-station-measurement-log.csv for the selected profile first."
  );
}

echo(str(
  "didgeridoo envelope — profile=", profile, " (", row_id, "), target=",
  target_hz, " Hz, blank length=", length_in, " in, quarter-wave=",
  quarter_wave_in, " in, mouth ID=", mouth_id_in, " in, bell/foot ID=",
  bell_id_in, " in — pending_measurement, NOT fabrication authority"
));

// ---- geometry ------------------------------------------------------------

module station_tick(x_mm, label_index) {
  translate([x_mm, 0, 0]) square([1.0, 18], center = true);
  translate([x_mm - 6, -18, 0]) rotate([0, 0, 90])
    text(station_labels[label_index], size = 4, halign = "right", valign = "center");
}

// Fallback used whenever a station's diameter is unresolved (TBD == -1).
// Same intent as CAD/bore-profile/didgeridoo-bore-starter.scad: a capture
// template, not a bore body.
module station_check_plate_2d() {
  length_mm = length_in * inch;
  translate([length_mm / 2, 0, 0]) square([length_mm, 0.5], center = true);
  for (i = [0 : len(station_pct) - 1]) {
    station_tick(station_pct[i] / 100 * length_mm, i);
  }
  translate([0, 18, 0])
    text(str("Didgeridoo envelope (", profile, "): interior stations unresolved"), size = 5);
  translate([0, 26, 0])
    text("Enable bell_show_assumption_curve, or measure+review a station table", size = 4);
}

// Lofts a stack of circular stations into a solid via consecutive hull()
// pairs — the standard OpenSCAD idiom for a horn/bore-shaped loft along Z.
module lofted_envelope(radii_mm, z_mm) {
  n = len(radii_mm);
  for (i = [0 : n - 2]) {
    hull() {
      translate([0, 0, z_mm[i]]) cylinder(h = 0.01, r = max(radii_mm[i], 0.01), $fn = 64);
      translate([0, 0, z_mm[i + 1]]) cylinder(h = 0.01, r = max(radii_mm[i + 1], 0.01), $fn = 64);
    }
  }
}

module bore_envelope_solid() {
  length_mm = length_in * inch;
  z_mm = [for (t = station_pct) t / 100 * length_mm];
  inner_r_mm = [for (d = interior_diameter_in) d / 2 * inch];
  outer_r_mm = [for (r = inner_r_mm) r + wall_thickness_in * inch];

  // Extend the inner (cavity) loft slightly past both ends so the bore
  // reads as open, not capped, at the mouthpiece and bell/foot faces.
  overcut_mm = 2 * inch;
  inner_z_ext = concat([z_mm[0] - overcut_mm], z_mm, [z_mm[len(z_mm) - 1] + overcut_mm]);
  inner_r_ext = concat([inner_r_mm[0]], inner_r_mm, [inner_r_mm[len(inner_r_mm) - 1]]);

  difference() {
    lofted_envelope(outer_r_mm, z_mm);
    lofted_envelope(inner_r_ext, inner_z_ext);
  }
}

if (has_all_stations(interior_diameter_in)) {
  bore_envelope_solid();
} else {
  station_check_plate_2d();
}

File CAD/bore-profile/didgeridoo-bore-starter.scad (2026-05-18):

// Didgeridoo bore profile starter.
// Status: non-fabrication B5 starter. No measured bore geometry is present.
// Fill measured_inner_diameter_in from analysis/bore-station-measurement-log.csv
// only after a reviewed measurement pass.

fabrication_mode = false;
inch = 25.4;

preview_length_in = 72;
station_t = [0, 0.05, 0.10, 0.20, 0.30, 0.40, 0.50, 0.60, 0.70, 0.80, 0.90, 1.00];
station_labels = [
  "BS-000", "BS-005", "BS-010", "BS-020", "BS-030", "BS-040",
  "BS-050", "BS-060", "BS-070", "BS-080", "BS-090", "BS-100"
];

// Sentinel -1 means unmeasured. Positive values may only come from the reviewed
// bore station log or a reviewed design-table export.
measured_inner_diameter_in = [-1, -1, -1, -1, -1, -1, -1, -1, -1, -1, -1, -1];

function has_all_measurements(v) = min(v) > 0;

if (fabrication_mode) {
  assert(
    has_all_measurements(measured_inner_diameter_in),
    "NO FABRICATION: populate measured_inner_diameter_in from reviewed bore-station data first."
  );
}

module station_tick(x_mm, label_index) {
  translate([x_mm, 0, 0]) square([1.0, 18], center = true);
  translate([x_mm - 6, -18, 0]) rotate([0, 0, 90])
    text(station_labels[label_index], size = 4, halign = "right", valign = "center");
}

module station_check_plate() {
  length_mm = preview_length_in * inch;
  translate([length_mm / 2, 0, 0]) square([length_mm, 0.5], center = true);
  for (i = [0 : len(station_t) - 1]) {
    station_tick(station_t[i] * length_mm, i);
  }
  translate([0, 18, 0])
    text("Didgeridoo bore stations: capture template only", size = 5);
  translate([0, 26, 0])
    text("No measured bore geometry or fabrication DXF in this starter", size = 4);
}

module measured_bore_envelope_2d() {
  length_mm = preview_length_in * inch;
  upper = [
    for (i = [0 : len(station_t) - 1])
      [station_t[i] * length_mm, measured_inner_diameter_in[i] * inch / 2]
  ];
  lower = [
    for (i = [len(station_t) - 1 : -1 : 0])
      [station_t[i] * length_mm, -measured_inner_diameter_in[i] * inch / 2]
  ];
  polygon(points = concat(upper, lower));
}

if (has_all_measurements(measured_inner_diameter_in)) {
  measured_bore_envelope_2d();
} else {
  station_check_plate();
}

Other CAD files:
CAD/Didgeridoos/Bi-Colored Assembly.SLDASM
CAD/Didgeridoos/All Together tersrt.SLDPRT
CAD/Didgeridoos/Small Block - Ash.SLDPRT
CAD/Didgeridoos/Drawings/Drawing of Four Diameters.SLDDRW

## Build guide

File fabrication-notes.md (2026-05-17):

# Fabrication Notes

Status: starter process notes, not a shop release.

## Process Order

1. Choose one validation candidate. Default: `DID-V5-A1-BELL-P0`.
2. Make a low-cost prototype or measurement coupon before hardwood work.
3. Measure actual bore ID at regular stations and record the data.
4. Install a removable beeswax mouthpiece and check for leaks.
5. Record cold and warmed-up drone pitch, then trim only from the open foot end.
6. Re-measure pitch and response after every trim.
7. Promote the measured station table into CAD/DXF/design-table authority only
   after the validation rows are complete.

## PVC Prototype Path

Use this when the next question is acoustic length and mouthpiece behavior.

- Cut long using the starter blank length.
- Deburr both ends; the player-contact edge must be smooth.
- Fit a removable wax mouthpiece.
- Record pitch before trimming.
- Trim the foot end in small increments; stop before the target is passed.

## Split-Blank Wood Path

Use this only after the prototype validates length and bore direction.

- Mill oversize stock.
- Split or route halves with clear centerline datums.
- Route the bore profile from a reviewed station table.
- Dry-fit and inspect for leak paths before adhesive.
- Glue with controlled clamping pressure and documented cure time.
- Turn/sand exterior only after the bore is sealed and inspected.

## Stave-Built Path

The stave-built path is the long-term design direction, but it is not V5
starter authority yet. Required upstream work:

- Convert the measured bore profile into inner polygon/stave widths.
- Decide stave count and bevel angle.
- Create a jig plan for repeatable bevel cuts.
- Validate that glue seams do not create air leaks along the bore.

## Safety Notes

- Do not play through uncured adhesive or finish.
- Remove sanding dust from the bore before any mouth contact.
- Treat reclaimed natural stalks as biological materials until cleaned and
  sealed.
- Keep finish claims product-specific and recorded at the time of use.

## Shop Unknowns

- Long straight drilling or routing method.
- Clamping method for full-length split blanks.
- Bore sanding reach.
- Whether a bell flare can be routed repeatably before a dedicated fixture.
- How much trim increment corresponds to cents change for the selected bore.

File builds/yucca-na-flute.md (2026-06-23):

# Yucca → Native-American (NAF) Style Flute Variant

> **Status: NEEDS CLARIFICATION**
>
> This document captures the concept and identifies the open acoustic questions. It is **not a complete build spec** — a tuned NA-style flute requires a bore-physics and finger-hole placement model that does not yet exist in this repo. Do not promise or attempt specific tuning without that calc. When the acoustic model is available, this document becomes the anchor for the full build spec.

---

## 1. Concept

Yucca stalks in the 1.5–2.5 in OD range (typically the upper zone of a tall stalk — see `stock-prep/cut-plan.md`) are promising candidates for a Native-American (NAF) style flute:

- **Length:** Upper zone sections are 18–30 in — within the typical NAF range for pentatonic minor scales in the G3–D4 octave.
- **Bore:** After pith clearance (see `stock-prep/bore-prep.md`), the internal bore diameter is 0.5–1.0 in — consistent with NAF bore dimensions.
- **Material:** Yucca's wall hardness is comparable to cedar or pine (common NAF materials); the natural surface is suitable for minimal finishing.
- **Acoustic pathway:** Standard 2-chamber NAF design — the air column in the lower chamber resonates through finger holes; the upper chamber and block direct airflow across the SAC (slow air chamber) gap.

This is a credible instrument concept. The construction pathway from materials to playable flute is clear in principle. What is missing is the calculation that translates bore diameter and length into finger-hole positions for a target key.

---

## 2. Open Acoustic Questions (Unblocking Conditions)

The following questions must be answered before a tuned build spec can be written. They are listed in dependency order.

### Q1 — Bore diameter and taper
- What is the effective bore diameter of a cleared yucca stalk at the range of upper-zone ODs (1.5–2.5 in OD)?
- Is the bore taper gradual enough to support a predictable resonant frequency, or must it be reamed to a straight bore?
- **Needed:** Measurement data from several cleared yucca upper-zone sections.

### Q2 — SAC geometry and flue dimensions
- What SAC (slow air chamber) length and flue gap dimensions are appropriate for the bore diameter found in Q1?
- The SAC is typically cut into the stalk or formed with a saddle block; yucca's wall thickness constrains the depth of this cut.
- **Needed:** Wall-thickness measurement at the mouthpiece end (where the SAC is cut) to confirm the cut is feasible.

### Q3 — Finger-hole placement for target key
- Given bore diameter, effective length, and SAC geometry, where must the finger holes be positioned to produce a pentatonic minor scale in the target key?
- This requires the NAF acoustic model (tone-hole position as a function of bore diameter, wall thickness, and effective length — the standard NAF calculator formulae).
- **Needed:** NAF bore-physics calculator, preferably implemented in the instrument-maker repository alongside the existing didgeridoo bore model. Route this request to instrument-maker if pursued.

### Q4 — Finger-hole sizing
- What diameter produces correct intonation at each hole position, accounting for yucca's wall thickness?
- Depends on Q3.

---

## 3. What Needs to Exist to Unblock This

| Blocker | Owner / Location |
|---|---|
| NAF bore-physics model (bore OD + length → effective acoustic length + finger-hole positions) | instrument-maker repo — parallel to the existing didgeridoo bore model |
| Measurement data: bore ID of cleared yucca upper-zone sections | this repo — gather during `stock-prep/bore-prep.md` execution |
| Wall-thickness measurement at mouthpiece zone | this repo — record during material grading (`stock-prep/material-spec.md`) |

Once these three inputs exist, a full tuned build spec can be authored as a revision to this document.

---

## 4. Provisional Build Concept (Not for Use Without Q1–Q4 Answered)

The steps below describe the physical construction sequence, contingent on the acoustic calc providing hole positions and diameters. They are captured here for completeness, not as current instructions.

1. **Select stalk section:** Upper zone, 18–30 in, OD 1.5–2.5 in, passes cure-check and material-spec grading.
2. **Clear bore (pith removal):** Follow `stock-prep/bore-prep.md`. Target bore ID per acoustic model output.
3. **Establish SAC and flue:**
   - Mark the SAC zone at ~1/3 of the stalk length from the mouthpiece end.
   - Cut the SAC channel to depth permitted by wall thickness.
   - Shape or carve a saddle block to direct airflow across the flue gap.
4. **Drill finger holes:** At positions from acoustic model output; use appropriate bit diameter per Q4.
5. **Tune and adjust:** Ream or cover holes as needed to correct intonation.
6. **Finish:** Light oil finish (boiled linseed); optionally wrap the mouthpiece zone and SAC block with cordage.

---

## 5. Safety Note

Pith removal and hole drilling in yucca releases calcium-oxalate raphides. Follow `safety/agave-dust.md` throughout construction.

---

## Cross-References

- Stalk zone selection: `stock-prep/cut-plan.md` (upper zone)
- Bore prep (pith clearance): `stock-prep/bore-prep.md`
- Acoustic model needed: instrument-maker repo bore-physics model (NAF variant — not yet built)
- Dust safety: `safety/agave-dust.md`

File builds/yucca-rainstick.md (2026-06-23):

# Yucca Rainstick Build Variant

Exploits yucca's built-in pith baffle to produce a rainstick without the spine-pin drilling step required in traditional cactus-cactus construction. The pith acts as a natural cascade obstruction: fill media tumbles through the partially-cleared pith channels, producing the characteristic rainfall sound.

> **Dust safety:** Yucca boring and sanding releases calcium-oxalate raphides. Wear a P100/N95 respirator, safety glasses, and long sleeves throughout. See `safety/agave-dust.md`.

---

## 1. How Yucca's Pith Works as a Baffle

In a cactus rainstick, thorns or dowels are inserted through the wall to create cascade obstructions inside a hollow tube. Yucca's interior pith is already a matrix of fibrous channels — partially clearing the pith creates the same obstruction pattern without drilling through the wall.

The goal is a **partial pith removal**: clear a central channel for fill-media flow, but leave 40–60% of the pith matrix intact as the baffle. Do not fully gouge the pith; that turns it into a hollow tube and kills the cascade effect.

---

## 2. Materials List

| Item | Spec / Notes |
|---|---|
| Yucca stalk section | Cured (pass `stock-prep/cure-check.md`); 24–60 in length; 2–4 in OD |
| Fill media (choose one or mix) | Small seeds (amaranth, rice, millet), dried pebbles (3–5 mm), glass beads |
| End-cap material | Cork stoppers, hardwood discs (1/4-in ply), or carved yucca plugs |
| Adhesive for end caps | Titebond III or 5-min epoxy |
| Finish (optional) | Boiled linseed oil, paste wax, or acrylic spray — protects outer cortex |
| Sandpaper | 80-grit and 150-grit for end faces and outer surface |
| Tools | Drill or hand borer, long drill bit or rebar (~1/4 in) for channel clearance, spoon gouge, flashlight for bore inspection |

---

## 3. Step-by-Step Procedure

### Step 1 — Select and Inspect the Stalk Section

1. Choose a cured yucca section 24–60 in long (see `stock-prep/cut-plan.md` — upper zone sections are ideal).
2. Confirm the section passes the cure-check: knuckle-tap rings clear end-to-end.
3. Check that the outer wall is structurally sound (no through-wall cracks).

### Step 2 — Square the Ends

1. Cross-cut both ends clean and square with a fine-tooth saw.
2. Sand the cut faces flat (80-grit, then 150-grit).
3. The end faces are where the caps will seat — they must be flat for a good seal.

### Step 3 — Partial Pith Clearance

1. From one end, use a long drill bit or a sharpened rebar rod to bore a central channel through the pith. Target: 3/4 – 1 in diameter channel down the centre axis.
2. Work in short passes, clearing debris frequently. Use a flashlight from the other end to gauge progress.
3. **Stop clearing when the channel is open end-to-end but the surrounding pith matrix is still present.** The pith should be visible as an irregular ring around the central channel when you look through it.
4. Shake the tube vertically — loose pith debris will fall out. Blow out dust.
5. Inspect with a flashlight: you should see the central channel flanked by pith baffle material on all sides.

> **Tip:** The amount of pith left in determines the cascade speed. More pith = slower, denser sound. Less pith = faster, lighter sound. Aim for ~50% of the pith cross-section intact on the first build.

### Step 4 — Test the Cascade (Dry Run)

1. Temporarily cap one end with your palm.
2. Add a small handful of fill media through the open end.
3. Tip the tube end-to-end slowly and listen. You should hear a steady, gradual cascade — not a single thump (too much pith cleared) and not silence (channel blocked).
4. Adjust pith clearance if needed:
   - Sound too abrupt → re-insert the borer and clear slightly more pith
   - No sound / no flow → the central channel is blocked; clear the obstruction

### Step 5 — Load Fill Media

1. Seal one end permanently (see Step 6) before loading.
2. Through the open end, pour in fill media. Standard fill: 2–4 tablespoons per foot of tube length as a starting point.
3. Adjust by ear: tip the tube and listen. Add more for a denser cascade, remove for a lighter one.

### Step 6 — End Caps

**Option A — Cork stoppers:** Select cork(s) that fit snugly in the bore opening. Dry-fit, then seat with a few drops of CA glue or epoxy around the perimeter. Let cure 24 h.

**Option B — Hardwood disc cap:** Cut a 1/4-in hardwood or ply disc to match the end OD. Glue and clamp with 5-min epoxy. Optionally add a recessed groove and ring of CA for a hermetic seal.

**Option C — Carved yucca plug:** Cut a short yucca section (2–3 in) slightly wider than the bore opening, carve to fit, and glue. Matches the look of the instrument body.

Seal both ends completely. Shake vigorously after curing to confirm no rattle from loose end-cap joints.

### Step 7 — Finish the Exterior (Optional)

1. Sand the outer cortex: 80-grit to remove weathering, 150-grit to smooth.
2. Apply a finish coat:
   - **Boiled linseed oil:** penetrating, matte. Apply thin coat, wipe excess, dry 48 h.
   - **Paste wax:** protective and brings out the natural colour.
   - **Acrylic spray:** quick, durable, available in satin or gloss.
3. Decorate as desired (pyrography, paint, wrapped cordage on handle zone).

---

## 4. Fill Media Options

| Media | Sound character | Notes |
|---|---|---|
| Dried amaranth / millet seeds | Soft, dense, long cascade | Lightweight; excellent for slow, rain-like effect |
| Dried rice | Medium density, crisp | Slightly louder; can absorb humidity — seal end caps well |
| Small pebbles (3–5 mm) | Louder, staccato | Good for outdoor performance; durable |
| Glass or wooden beads | Bright, articulate | Most consistent; heaviest; produce the most percussion-like sound |
| Mix (seeds + beads) | Layered texture | Seeds for soft base, beads for articulate top end |

Fill media can be replaced by removing one end cap. Design for removability if experimentation is planned.

---

## 5. Acceptance Criteria

| Check | Pass |
|---|---|
| Cascade sound | Steady rainfall cascade from end to end, ~3–8 s travel time |
| No rattle | End caps and seams produce no loose joint noise |
| No leakage | Shake vigorously — no fill media escapes from end caps or wall cracks |
| Working pith baffle | Sound is noticeably more gradual than a hollow tube would produce |

---

## Cross-References

- Stalk cure check before starting: `stock-prep/cure-check.md`
- Stalk grading: `stock-prep/material-spec.md`
- Cut-zone selection (upper zone): `stock-prep/cut-plan.md`
- Dust/raphide safety: `safety/agave-dust.md`

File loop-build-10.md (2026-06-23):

# Build Loop — tonykoop/didgeridoo / Epic #10: Agave & yucca as instrument stock - material prep & multi-cut

You are draining this epic autonomously. Read this whole file first, then work the
loop below until the termination signal. Do not ask for confirmation on anything
covered here — it is already decided.

## What to work on
- Implement the **lowest-numbered open story** under Epic #10, in numeric order.
- **Skip already-done work FIRST.** Before implementing a story, check for a MERGED
  PR that references it (`Closes #<n>` / `Refs #<n>` / `feat(#<n>)`). If one exists,
  the story is done: comment "already delivered by PR #X", make sure the issue is
  closed, and move to the next. Never re-implement finished work.
- Also skip any story that already has an **open PR** (work in flight) — don't duplicate it.
- If **every** story under this epic is already closed / merged / in-PR, do not start —
  emit `DOMAIN DRAINED: tonykoop/didgeridoo/#10 (already complete)` and stop.
- Each open story has an `## Implementation plan` — follow it. It names the files,
  interfaces, and tests. You are transcribing a finished design, not redesigning it.
  If a plan is genuinely missing or wrong, comment on the story, skip it, move on.

## Branch + PR
- Branch off clean `main` for every story: `git switch -c feat/10-<short-name>`.
- One story → one branch → one PR. Never bundle stories.
- PR title: `feat(#10): <story title>`.
- PR body: start with `Closes #<story-number>` so the merge auto-closes the story
  (the human still merges, so they stay the gate). Then 2–4 bullets: what changed,
  files touched, how it was verified.
- Never `Closes` the epic (#10) — epics close in the reconcile sweep when all
  their stories are closed.

## Merge + isolation
- **Never self-merge.** Open the PR and move on. The human merges.
- Always branch from `main`, never from another feature branch. Each branch recreates
  what it needs — duplicate a small type rather than depend on an unmerged branch. Do
  not rebase against unmerged sibling PRs.

## Guardrails — STOP and ask before any of these
- Touching files outside this epic's scope, or refactoring/renaming shared code.
- Changing repo visibility, pushing to a public repo, or cross-linking a private repo
  from a public one (IP firewall).
- Deleting data, force-pushing, rewriting history, or committing a secret.

## How to work
- Work **directly** in this one context. **No sub-agents, no Task tool.**
- Prefer **additive** changes (new file / new section) over refactors or renames.
- Verify after every change with the fast suite, then move on:
  - Test: validate changed json/csv/markdown (docs/data repo — no code suite)   (keep under ~10s; CI is the real gate)
  - Lint: —
- After opening each PR, append one line to `loop-progress.md` at the repo root:
  `#<story> -> PR #<pr> (<short note>)`. Makes the sprint resumable after a compaction
  or crash — the next session reads it plus the skip-done check.
- A story is done when its acceptance criteria pass and the suite is green.

## Stop & escalate (break the loop and surface it)
- A spec is ambiguous/contradictory in a way the implementation plan doesn't resolve.
- A story would require a Guardrails action above.
- You've been blocked on the same thing twice — stop and report; don't thrash.

## Termination signal
- When **every** story under Epic #10 has an open PR (or is already closed/merged),
  stop and emit exactly:

  `DOMAIN DRAINED: tonykoop/didgeridoo/#10`

- Then summarize the PRs you opened. Do not start unrelated work.

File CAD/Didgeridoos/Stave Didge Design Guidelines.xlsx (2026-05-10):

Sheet: GlobalVariables
Board Thickness (in): | 0.75
Number of Staves: | 6 | Stave Bevel (180/n): | 30.00
Flare to Drone Ratio: | 0.3333333333
Degree of Flare (φ): | 9.50
Bevel Angle: | 29.547 | Bevel Compliment: | 60.453
Crosscut Angle: | 5.443
Stave A Extra Length (in): | 1.00
Stave B Extra Length (in): | 0.00
Wood Type 1 ($/in^3) | $0.150
Wood Type 2 ($/in^3) | $0.150
Saw Blade Kerf (in): | 0.095
Horizontal Kerf (in): | 0.1097
Dado Depth (in): | 0.375

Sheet: Design Table
Key | Nominal Total Length (in) | Nominal Diameter (in) | R - Circumradius (in) | r - Inradius (in) | Nominal Drone Length (in) | ISWA - Inner Stave Width (in) | OSWA - Outer Stave Width (in) | Slant Length (in) | BCR - Base Circum-Radius (in) | JISW - Min Inner Width (in) | JOSW - Min Outer Width (in) | BISW - Max Inner Width (in) | BOSW - Max Outer Width (in)
01. C3 | 36.00 | 1.25 | 0.62 | 0.54 | 27.00 | 0.62 | 1.491 | 9.12 | 1.75 | 0.62 | 1.62 | 0.88 | 1.74
02. B2 | 38.00 | 1.25 | 0.62 | 0.54 | 28.58 | 0.62 | 1.491 | 9.66 | 1.82 | 0.62 | 1.62 | 0.91 | 1.78
03. A2# | 40.25 | 1.25 | 0.62 | 0.54 | 30.23 | 0.62 | 1.491 | 10.22 | 1.89 | 0.62 | 1.62 | 0.94 | 1.81
04. A2 | 42.75 | 1.25 | 0.62 | 0.54 | 32.03 | 0.62 | 1.491 | 10.83 | 1.97 | 0.62 | 1.62 | 0.98 | 1.85
05. G2# | 45.25 | 1.50 | 0.75 | 0.65 | 33.99 | 0.75 | 1.616 | 11.49 | 2.17 | 0.75 | 1.75 | 1.09 | 1.95
06. G2 | 48.00 | 1.50 | 0.75 | 0.65 | 35.98 | 0.75 | 1.616 | 12.16 | 2.25 | 0.75 | 1.75 | 1.13 | 1.99
07. F2# | 50.75 | 1.50 | 0.75 | 0.65 | 38.10 | 0.75 | 1.616 | 12.88 | 2.34 | 0.75 | 1.75 | 1.17 | 2.04
08. F2 | 53.75 | 1.50 | 0.75 | 0.65 | 40.33 | 0.75 | 1.616 | 13.63 | 2.44 | 0.75 | 1.75 | 1.22 | 2.08
09. E2 | 57.00 | 1.75 | 0.88 | 0.76 | 42.78 | 0.87 | 1.741 | 14.46 | 2.67 | 0.87 | 1.87 | 1.33 | 2.20
10. D2# | 60.50 | 1.75 | 0.88 | 0.76 | 45.30 | 0.87 | 1.741 | 15.31 | 2.77 | 0.87 | 1.87 | 1.38 | 2.25
11. D2 | 64.00 | 1.75 | 0.88 | 0.76 | 47.95 | 0.87 | 1.741 | 16.21 | 2.88 | 0.87 | 1.87 | 1.44 | 2.31
12. C2# | 67.75 | 2.00 | 1.00 | 0.87 | 50.85 | 1.00 | 1.866 | 17.19 | 3.13 | 1.00 | 2.00 | 1.56 | 2.43
13. C2 | 71.75 | 2.00 | 1.00 | 0.87 | 53.85 | 1.00 | 1.866 | 18.20 | 3.25 | 1.00 | 2.00 | 1.63 | 2.49
14. B1 | 76.00 | 2.00 | 1.00 | 0.87 | 57.00 | 1.00 | 1.866 | 19.27 | 3.39 | 1.00 | 2.00 | 1.69 | 2.56
15. A1# | 80.50 | 2.25 | 1.12 | 0.97 | 60.44 | 1.12 | 1.991 | 20.43 | 3.65 | 1.12 | 2.12 | 1.83 | 2.69
16. A1 | 85.25 | 2.25 | 1.12 | 0.97 | 63.99 | 1.12 | 1.991 | 21.63 | 3.80 | 1.12 | 2.12 | 1.90 | 2.77
17. G1# | 90.25 | 2.25 | 1.12 | 0.97 | 67.76 | 1.12 | 1.991 | 22.90 | 3.96 | 1.12 | 2.12 | 1.98 | 2.85
18. G1 | 95.75 | 2.25 | 1.12 | 0.97 | 71.74 | 1.12 | 1.991 | 24.25 | 4.13 | 1.12 | 2.12 | 2.06 | 2.93
19. F1# | 101.25 | 2.25 | 1.12 | 0.97 | 75.97 | 1.12 | 1.991 | 25.67 | 4.30 | 1.12 | 2.12 | 2.15 | 3.02
20. F1 | 107.25 | 2.50 | 1.25 | 1.08 | 80.51 | 1.25 | 2.116 | 27.21 | 4.62 | 1.25 | 2.25 | 2.31 | 3.18
21. E1 | 113.75 | 2.50 | 1.25 | 1.08 | 85.27 | 1.25 | 2.116 | 28.82 | 4.82 | 1.25 | 2.25 | 2.41 | 3.27
22. D1# | 120.50 | 2.50 | 1.25 | 1.08 | 90.29 | 1.25 | 2.116 | 30.52 | 5.03 | 1.25 | 2.25 | 2.51 | 3.38
23. D1 | 127.50 | 2.50 | 1.25 | 1.08 | 95.61 | 1.25 | 2.12 | 32.31 | 5.25 | 1.25 | 2.25 | 2.62 | 3.49
24. C1# | 135.00 | 2.50 | 1.25 | 1.08 | 101.25 | 1.25 | 2.116 | 34.22 | 5.49 | 1.25 | 2.25 | 2.74 | 3.61
25. C1 | 143.00 | 2.50 | 1.25 | 1.08 | 107.24 | 1.25 | 2.116 | 36.24 | 5.74 | 1.25 | 2.25 | 2.87 | 3.73
 |  |  |  |  |  |  |  |  |  |  | double check "0.75"?

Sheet: Aspect Ratios
 | Temperature (°C) |  | 37
 | Speed of Sound (m/s) |  | 353.8
 | X Factor |  | 0.3
Key | Frequency (Hz) | Wavelength (in) | Build Length (in) | ID AR 26:1 | ID AR 24:1 | ID AR 22:1 | Build ID (in) | Actual Aspect Ratio:
01. C3 | 130.81 | 26.62 | 27.00 | 1.04 | 1.12 | 1.23 | 1.25 | 21.60
02. B2 | 123.47 | 28.20 | 28.58 | 1.10 | 1.19 | 1.30 | 1.25 | 22.86
03. A2# | 116.64 | 29.85 | 30.23 | 1.16 | 1.26 | 1.37 | 1.25 | 24.18
04. A2 | 110.00 | 31.66 | 32.03 | 1.23 | 1.33 | 1.46 | 1.25 | 25.63
05. G2# | 103.82 | 33.54 | 33.99 | 1.31 | 1.42 | 1.55 | 1.50 | 22.66
06. G2 | 98.00 | 35.53 | 35.98 | 1.38 | 1.50 | 1.64 | 1.50 | 23.99
07. F2# | 92.50 | 37.65 | 38.10 | 1.47 | 1.59 | 1.73 | 1.50 | 25.40
08. F2 | 87.31 | 39.88 | 40.33 | 1.55 | 1.68 | 1.83 | 1.50 | 26.89
09. E2 | 82.41 | 42.26 | 42.78 | 1.65 | 1.78 | 1.94 | 1.75 | 24.45
10. D2# | 77.78 | 44.77 | 45.30 | 1.74 | 1.89 | 2.06 | 1.75 | 25.88
11. D2 | 73.42 | 47.43 | 47.95 | 1.84 | 2.00 | 2.18 | 1.75 | 27.40
12. C2# | 69.30 | 50.25 | 50.85 | 1.96 | 2.12 | 2.31 | 2.00 | 25.42
13. C2 | 65.40 | 53.25 | 53.85 | 2.07 | 2.24 | 2.45 | 2.00 | 26.92
14. B1 | 61.74 | 56.40 | 57.00 | 2.19 | 2.38 | 2.59 | 2.00 | 28.50
15. A1# | 58.27 | 59.76 | 60.44 | 2.32 | 2.52 | 2.75 | 2.25 | 26.86
16. A1 | 55.00 | 63.31 | 63.99 | 2.46 | 2.67 | 2.91 | 2.25 | 28.44
17. G1# | 51.91 | 67.08 | 67.76 | 2.61 | 2.82 | 3.08 | 2.25 | 30.11
18. G1 | 49.00 | 71.07 | 71.74 | 2.76 | 2.99 | 3.26 | 2.25 | 31.89
19. F1# | 46.25 | 75.29 | 75.97 | 2.92 | 3.17 | 3.45 | 2.25 | 33.76
20. F1 | 43.66 | 79.76 | 80.51 | 3.10 | 3.35 | 3.66 | 2.50 | 32.20
21. E1 | 41.20 | 84.52 | 85.27 | 3.28 | 3.55 | 3.88 | 2.50 | 34.11
22. D1# | 38.89 | 89.54 | 90.29 | 3.47 | 3.76 | 4.10 | 2.50 | 36.12
23. D1 | 36.71 | 94.86 | 95.61 | 3.68 | 3.98 | 4.35 | 2.50 | 38.24
24. C1# | 34.65 | 100.50 | 101.25 | 3.89 | 4.22 | 4.60 | 2.50 | 40.50
25. C1 | 32.70 | 106.49 | 107.24 | 4.12 | 4.47 | 4.87 | 2.50 | 42.90

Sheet: Method
Step | Tool | Set Up | Stave | Face
Lengthwise Straight Edge Rip | Radial Arm Saw | Conserve AMAP
Stencil | Pencil & Tape Measure |  | A & B | none
Rip: A1, A2, A3 | Radial Arm Saw | 30 degree bevel rip | A | Right & Left
Rip: B1-B3 | Radial Arm Saw | 30 degree bevel rip | B | Right
Xcut: Tops of A1-A3 | Radial Arm Saw | 90 degree Xcut | A | Top
Xcut: Tops and Bottoms of B1-B3 | Radial Arm Saw
Dowel Bore into end grain: A1-A3 | Drill Press | 1/4" Bit
Dowel Bore w/ 9.5 degree Jig: B1-B3 | Drill Press | 1/4" Bit
45 Miter: A1-A3 | Radial Arm Saw
Flute: A1-A3 | Router
35.5 Miter: Tops of B1-B3 | Radial Arm Saw
2013-05-25
Screw the work above, just send it to a CNC Shop
http://www.thiedewoodworks.com/
Sheet Size
Length | Width | Price/Sheet | Price per square foot
4 | 8 | 29 | 0.90625
5 | 8 | 34 | 0.85
4 | 10 | 37 | 0.925
3 | 12 | 35 | 0.9722222222
5 | 5 | 27 | 1.08
Stencil Information
Stenciled on Endgrain | \ A1 / | / A2 \ | \ A3 / | /B1:B3\ | Glue Up:
Stenciled on Face |  |  |  |  | A1 | B1
Wood Type 1 |  | Wood Type 2 |  |  | A1 | B1
A1 |  | A1 |  |  | A2 | B2
A2 - Finish Side Down |  | A2 - Finish Side Down |  |  | A2 | B2
A3 |  | A3 |  |  | A3 | B3
B1:B3 - Finish Side Down |  | B1:B3 - Finish Side Down |  |  | A3 | B3
Note: A2 & B1:B3 are oriented with finish side down when looking at stenciled face of board.

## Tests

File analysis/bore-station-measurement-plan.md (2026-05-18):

# Bore Station Measurement Plan

Status: B5 planning packet. This file defines how to capture bore geometry; it
does not assert measured bore dimensions.

## Authority Boundary

The current repo contains a 2013 notebook photo, a workbook-derived CNC design
table, legacy SolidWorks files, and shop photos. Those are useful evidence, but
the clean repo does not yet contain a reviewed station-by-station bore profile.
Until `analysis/bore-station-measurement-log.csv` is populated from a physical
blank or a reviewed design table, OpenSCAD and DXF outputs are starter
templates only.

## Station Datum

- `BS-000` is the mouthpiece seal plane after any beeswax or mouthpiece insert
  datum is defined.
- `BS-100` is the open foot end after the blank is cut long but before final
  pitch-trimming.
- Intermediate stations are normalized percentages of effective body length.
  The actual axial positions must be calculated from a measured blank length,
  not guessed from photos.

## Measurement Method

1. Choose one physical blank or one reviewed design-table row and assign a
   stable `blank_id`.
2. Measure the body length from the mouthpiece datum to the foot datum.
3. Convert each normalized station in
   `analysis/bore-station-station-map.csv` to an axial position in inches.
4. At each station, record major and minor inner diameters, wall thickness if
   reachable, tool type, repeat count, temperature, humidity, and photo ID.
5. Mark `authority_status` as `measured_pending_review` until a human review
   signs off the row and any derived OpenSCAD/DXF output.

## CAD Handoff

`CAD/bore-profile/didgeridoo-bore-starter.scad` is a non-fabrication starter.
It can render a station-check plate and can be turned into a bore envelope only
after all station diameters are filled with positive measured values. Any DXF
export must be registered in `visual-output-register.csv` and must trace back
to the populated measurement log or a reviewed design table.

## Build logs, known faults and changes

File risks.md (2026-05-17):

# Risks

Current status: bare-bones readiness packet. Risks below are gates for the
next validation build, not proof that the current packet is build-ready.

## Acoustic Risks

- The stopped-pipe quarter-wave model omits mouthpiece compliance, player
  coupling, bell end correction, bore roughness, leaks, and warm-breath
  temperature effects.
- The A1 bell candidate may not trim predictably if the bell flare dominates
  the end correction.
- Ideal 3f and 5f resonance expectations may not match playable toot response.

## Fabrication Risks

- Long-bore ID measurements may be sparse or hard to reproduce without a
  dedicated gauge rod, bore scope, or station jig.
- Split-blank or stave glue-up may introduce leak paths that invalidate pitch
  measurements.
- Hardwood machining before a PVC or scrap validation pass could waste
  material on unverified geometry.

## Safety Risks

- Bore finishes, adhesives, sanding dust, and wax additives are breath-contact
  hazards until product choice, cure, odor, tack, and dust checks are recorded.
- A natural agave or found-bore path may include cracks, residue, or biological
  material that must be cleaned and inspected before play.

## Scope Risks

- Updating the README status to `V5 build-packet candidate` before CAD/DXF,
  visual register, validation rows, and MCP provenance exist would overstate
  readiness.
- Generated or rendered images may communicate shape, but they cannot control
  bore dimensions or toolpaths.

## Mitigations

- Keep the first build as PVC, scrap, or otherwise inexpensive validation stock.
- Record cold and warmed pitch before trimming.
- Promote only measured station data, reviewed CAD, DXF, or design tables to
  fabrication authority.
- Leave sourcing rows unverified until purchase time.

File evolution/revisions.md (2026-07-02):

# Revision Register — didgeridoo

| Rev | Date | Parent | Delta | Downstream artifacts invalidated |
| --- | --- | --- | --- | --- |
| A | 2026-07-01 | — | Stage 0 intake of current masters (`CAD/didgeridoo.scad` new envelope master + `CAD/bore-profile/didgeridoo-bore-starter.scad` station-capture template + `didgeridoo-design-table.xlsx`). | none (no alpha/beta/production artifacts exist yet) |

Stage 0 only. Gate A has not been run; no Alpha compiles, vendor quotes, or production lock exist for this product.

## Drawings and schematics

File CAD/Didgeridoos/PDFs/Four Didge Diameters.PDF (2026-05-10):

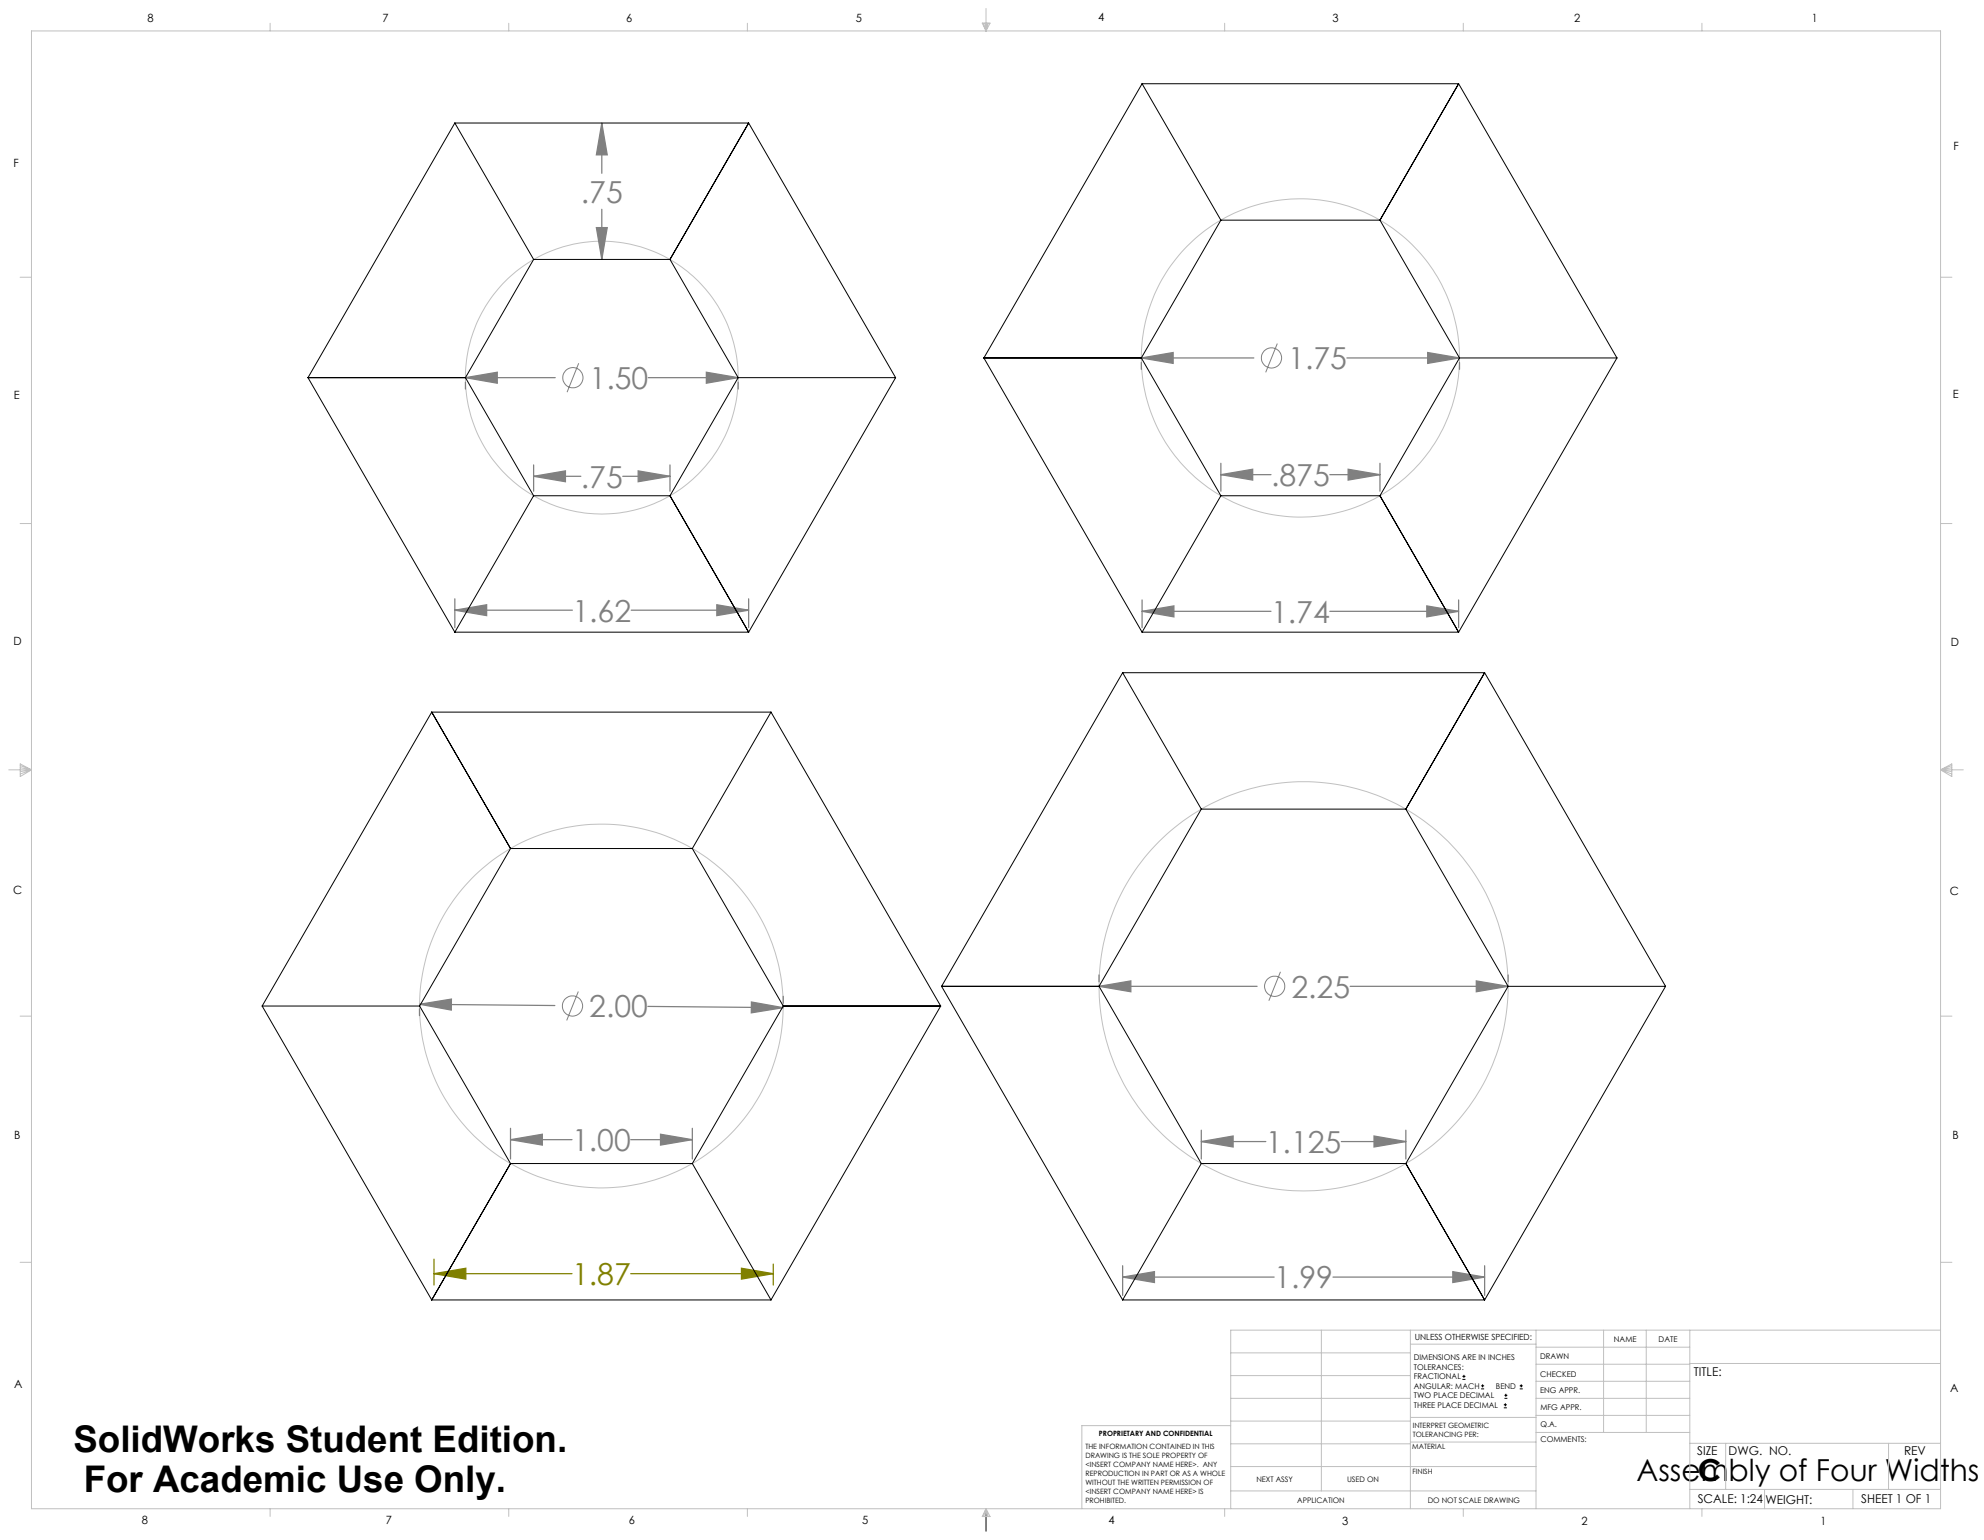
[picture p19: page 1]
SHEET 1 OF 1; SCALE: 1:24 WEIGHT:; DWG. NO.; REV; INTERPRET GEOMETRIC TOLERANCING PER:; ANGULAR: MACH; BEND; NEXT ASSY; USED ON

UNLESS OTHERWISE SPECIFIED:

DIMENSIONS ARE IN INCHES
TOLERANCES:
FRACTIONAL
TWO PLACE DECIMAL
THREE PLACE DECIMAL

DRAWN
CHECKED
ENG APPR.
MFG APPR.
COMMENTS:
Assembly of Four Widths

SolidWorks Student Edition.
For Academic Use Only.

PROPRIETARY AND CONFIDENTIAL
THE INFORMATION CONTAINED IN THIS
DRAWING IS THE SOLE PROPERTY OF
<INSERT COMPANY NAME HERE>. ANY
REPRODUCTION IN PART OR AS A WHOLE
WITHOUT THE WRITTEN PERMISSION OF
<INSERT COMPANY NAME HERE> IS
PROHIBITED.

DO NOT SCALE DRAWING

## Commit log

2026-04-25 Add 2021-2022 stave glue-up and raw-stock photos
2026-04-26 Wire up 2013 notebook entry photo (was a broken ref)
2026-05-02 Add Didgeridoo design table from Musical Instruments workbook
    [didgeridoo-design-table.xlsx]
2026-05-17 Add didgeridoo V5 starter packet (#2)
    Merge PR #2 as an honest L1 didgeridoo starter packet.
    This deliberately does not close issue #1. The merged packet adds the V4/root starter files, acoustic-law and visual-authority registers, validation gates, Wolfram starter notes, and MCP/CAD authority plans while keeping fabrication authority unreleased until measured bore data, reviewed CAD/DXF/design-table authority, render/print-packet artifacts, and real design MCP provenance exist.
    [bom.csv, bore-profile-register.csv, cut-list.csv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]
2026-05-18 Add didgeridoo bore station authority plan (#3)
    [bore-station-authority-register.csv, bore-station-measurement-log.csv, bore-station-station-map.csv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]
2026-05-18 Add didgeridoo Round 30 explorer readiness (#5)
    [validation.csv, visual-output-register.csv]
2026-05-23 Recover from 2026-05-18 hygiene-bot stash; restore 22 SolidWorks + xlsx/PDF files under CAD/Didgeridoos/
    [All Together Test.SLDPRT, All Together tersrt.SLDPRT, All Together.SLDASM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]
2026-05-31 wolfram-rename(didgeridoo): unique {slug}-starter.wl + dedupe + ref fixes (cloud-sync naming) (#6)
    [Didgeridoos.xlsx]
2026-05-31 Add image-gen concept prompt; wire explorer images
2026-06-23 feat(#10): material-selection spec & grading rubric
2026-06-23 feat(#10): split-and-glue bore-prep method
2026-06-23 feat(wolfram): deploy interactive model + live explorer embed (#9)
    * feat: deploy Wolfram bore-acoustic model and wire live interactive embed
    Deploy `didgeridoo-bore-acoustics.wl` (stopped-pipe L1 model, CloudDeploy-ready). Regenerate `explorer.html` with live iframe embed.
    Refs tonykoop/instrument-maker#197
    * feat(v5): wire didgeridoo-bore-acoustics.wl into engineering.wolfram manifest
    Adds second wolfram[] entry in capstone-manifest.json pointing to the
    stopped-pipe .wl model (cloud_url pending); keeps existing study-notes entry.
    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
2026-06-23 feat(#10): multi-cut yield planner (base/mid/upper) (#19)
2026-07-02 V5 packet refresh: status line, provenance, parametric OpenSCAD master, evolution intake
    - README.md: added machine-readable **Status:** L1 concept packet line
    (kept existing "## Status" prose/caveats intact).
    - CAD/didgeridoo.scad: new parametric bore-flare envelope master.
    Cylindrical/conical families are exact-by-definition from family-spec.csv
    mouth/bell IDs; bell family interior uses one labeled ASSUMPTION flare
    curve (no interior taper data exists in this repo — every station in
    analysis/bore-station-measurement-log.csv is still unmeasured) and falls
    back to a 2D station-check plate if that assumption is disabled. Does not
    replace CAD/bore-profile/didgeridoo-bore-starte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
    [didgeridoo.scad, visual-output-register.csv]
2026-07-03 chore: add .gitattributes for CRLF normalization + binary handling (#27)
    Adds the standard maker/CAD .gitattributes template (text=auto eol=lf,
    explicit LF for code/docs/config, binary excludes for CAD/image/office
    formats) so this repo stops being exposed to CRLF drift when edited by
    both Windows tools and WSL.
    Does NOT renormalize existing tracked blobs (git add --renormalize) —
    that is a deliberate, separately-reviewed follow-up per the tracking
    issue, to avoid a surprise mass line-ending diff in this PR.
    Refs tonykoop/instrument-maker#215
